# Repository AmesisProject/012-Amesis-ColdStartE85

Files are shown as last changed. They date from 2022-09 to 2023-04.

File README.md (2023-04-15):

# 012-Amesis-ColdStartE85
 Version 1.00 du document ( Vous pouvez me commander des PCB, faites vos demandes à amesisproject@gmail.com)
 
012-Amesis-ColdStartE85
Module d’aide au démarrage à froid pour les moteurs utilisant le carburant Superéthanol E85 dont la cartographie de démarrage à froid n’a pas été réglé.
Les conventions des moteurs à l’éthanol ont généralement un souci mangeur, c’est le ColdStart.

En effet, l’éthanol à son point éclaire à 7 degrés contre -40 pour le super sans plomb. Ce qui entraine donc un démarrage plus difficile voire impossible. 

Module mise au point pour le moteur de Golf IV 1.6L 16v essence passé à l’E85. Equipé du calculateur Magneti Marelli 4MV, mais peut fonctionner sur d’autre model tel quel. A vous d’analyser vos capteurs et signaux pour modifier le code.   

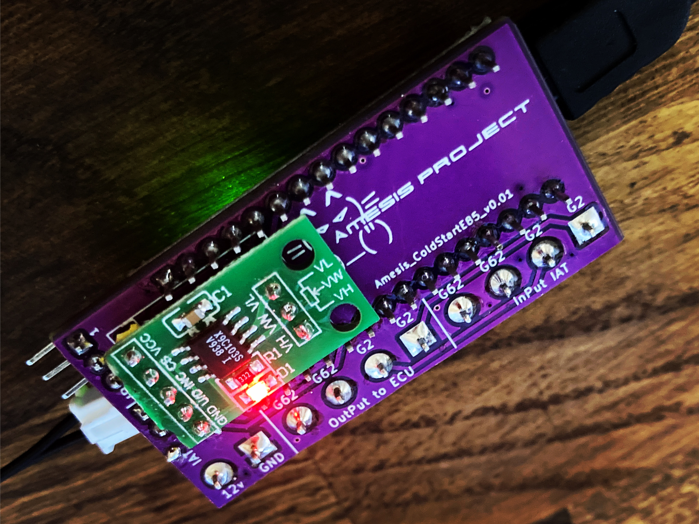
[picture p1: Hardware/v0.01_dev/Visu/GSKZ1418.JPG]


## I Avertissement
 
Ce module n’est nullement homologué, il sera donc fourni à but de test et non à une utilisation sur voie public.
 
Ce module modifiant le signal d’un capteur d’origine, les possibilités d’endommagement de l’ECU ou du moteur reste donc une éventualité. Vous restez seul responsable de l’utilisation de ce module. 
 
Ce module agissant sur des capteurs d’origine du véhicule pourrait entrainer des codes défaut moteur intermittent ou permanant, dans ce cas il est déconseillé de l’utiliser. 
 
Le module a pour but de décaler la plage de temperature du liquide de refroidissement ce qui correspond à des valeurs d’injection et d’allumage plus importante dans les cartographies moteur. Ces cartographies sont généralement très difficiles à modifier car le mappeur doit attendre une température adéquate pour son réglage car le moindre démarrage moteur réchauffe instantanément et rapidement le moteur du fait de la compression de l’air et de la combustion. Il faut attendre plusieurs heures afin de retenter un nouveau réglage, ce qui est parfois laborieux pour les mappeurs. 

C’est donc pour cela que ce module a été créer. 
 
De plus les cartographies de démarrage à froid « cold star » sur les calculateurs ECU Magneti Marelli 4MV sont encore un mystère dans notre communauté.

Cette documentation consterne le module en version matériel 
HW : v0.01dev et logiciel
SW Firmware : v1.031 Béta

Ce module est en version Beta, il sera donc apprécié tout retour d’information positif ou négatif à son sujet pour des nouvelle amélioration matériel et logiciel. 
Vous pouvez nous faire une proposition de modification de cade pas « Pull Requests » de GitHub ou de nous informer sur n’importe quel sujet, problème, bug et améliorations à venir, dans la partie « Issues ». Du repos GitHub du projet « 012-Amesis-ColdStartE85 »
https://github.com/AmesisProject/012-Amesis-ColdStartE85

## II Schéma de câblage
 
Type de branchement possible
Chercher et trouver la sonde de temperature du liquide de refroidissement.
 
La sonde G2 chez le groupe VAG informe la temperature au compteur.
 
La sonde G62 chez le groupe VAG informe la temperature au calculateur moteur (ECU).
 
Pour ce module c’est la sonde de temperature moteur qui nous intéresse. 
 
Ceci a été tester sur une Golf IV 1.6L 16s équipé d’un ECU Magneti Marelli. Ce qui est impotent c’est que la sonde de température du véhicule soit de type NTC c’est à dire que plus elle se réchauffe plus sa résistance réduit (plus elle se rapproche de 0.00 Ohm).
 
Le module doit être raccordé à un plus après contacte et protégé par un fusible 1A (à vérifier suivant la consommation de courant du module) :
 
1)	Sonde à 2 fils (nommer G62 chez le groupe VAG)
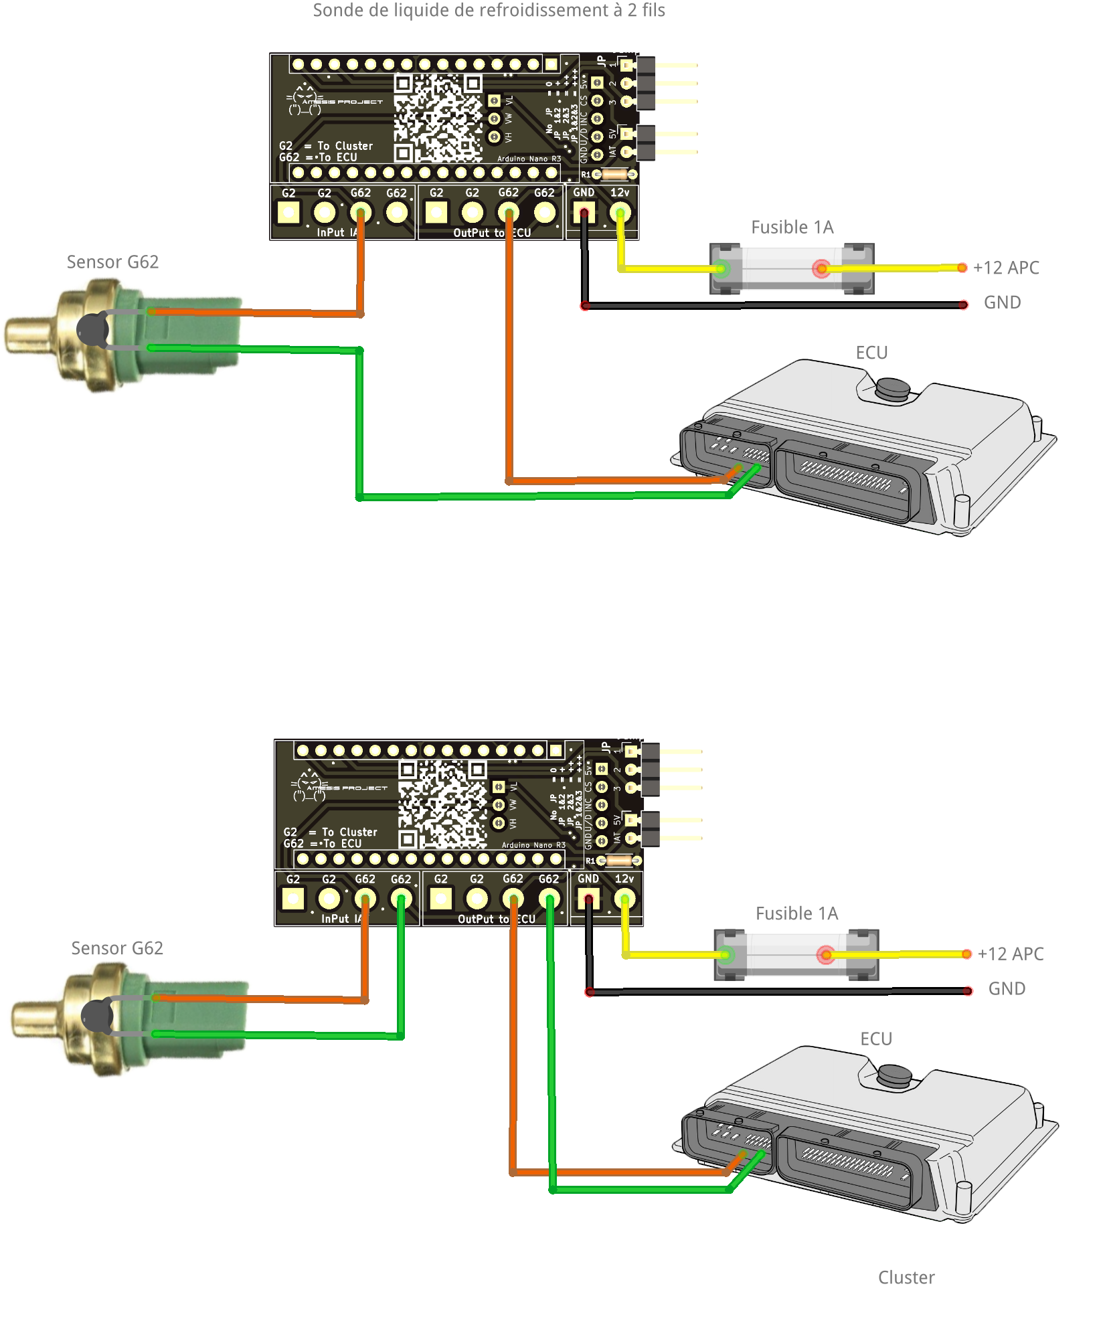
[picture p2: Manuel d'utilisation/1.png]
 
 
2)	Sonde à 4 fils (nommer G2 et G62 chez lez groupe VAG, les deux sondes sont dans le même boitier)
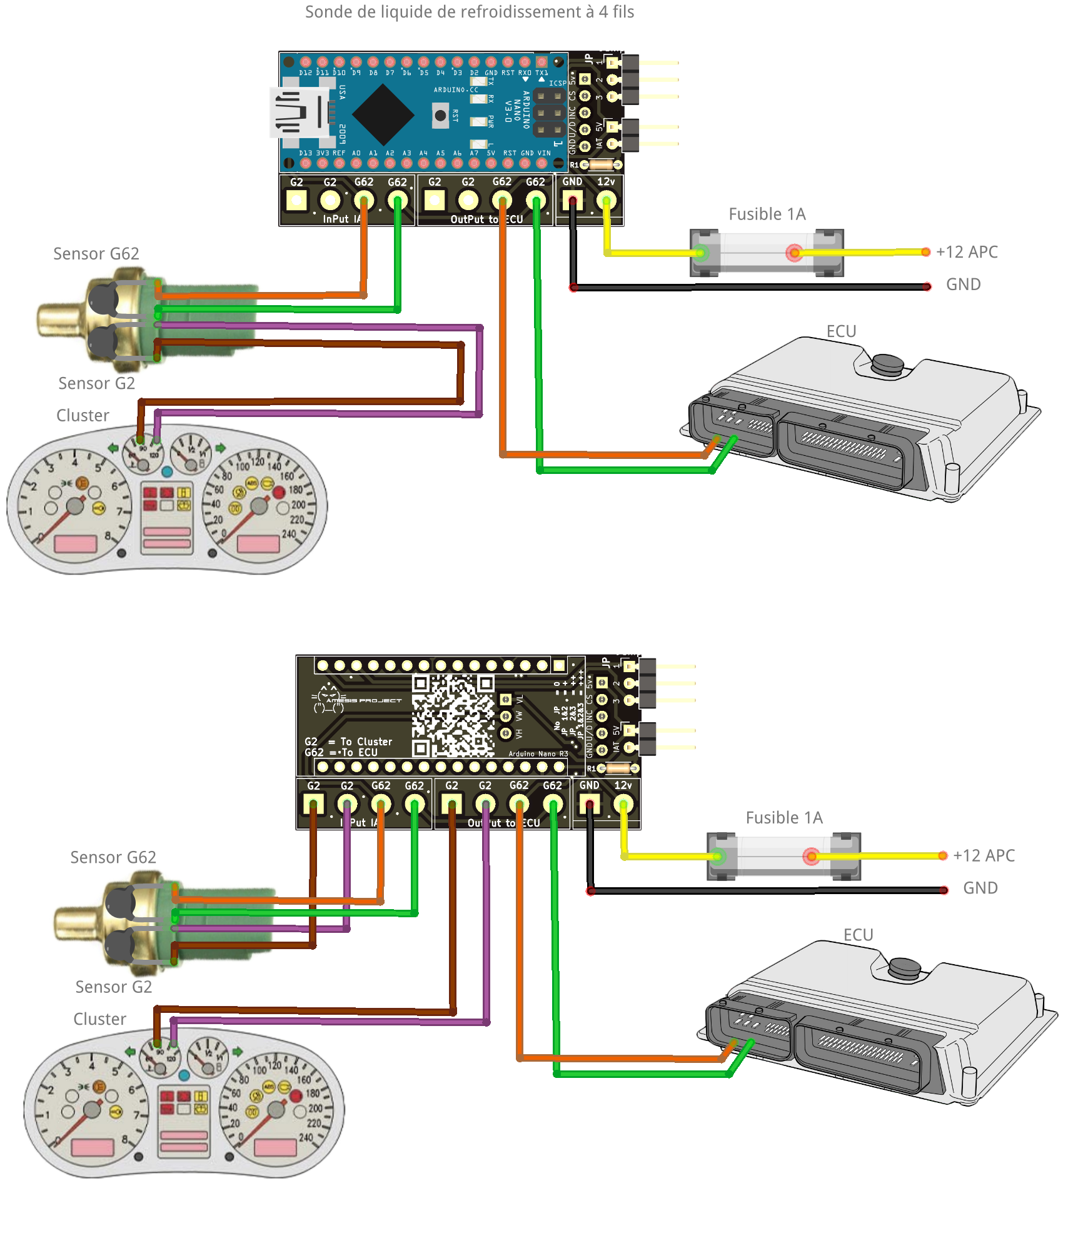
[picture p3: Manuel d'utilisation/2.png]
 

## III Options du module
 
  Le module est équipé des trois Pins accessible, se qui permet de sélectionner les options.
1)	 Option 1
Aucun jumpeur d’installer :
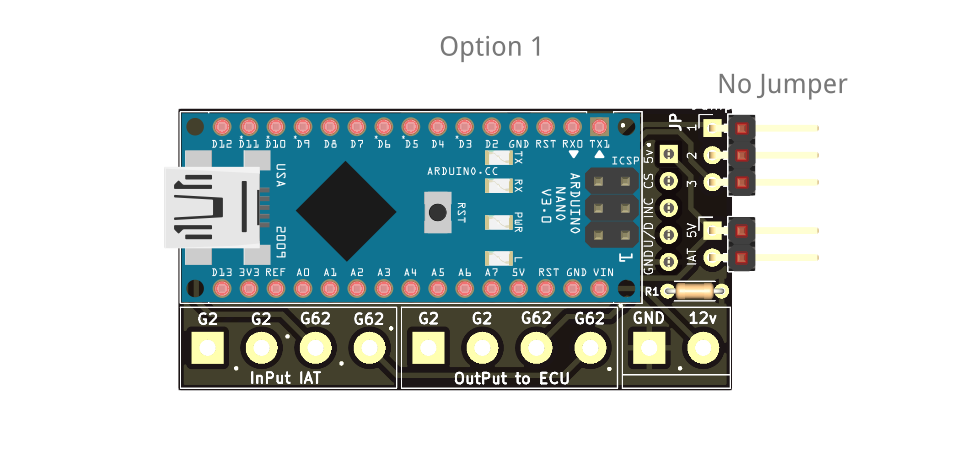
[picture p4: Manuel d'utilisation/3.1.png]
  
Dans ce cas, le module et inactif, une fois le contacte mis, il lesse passe le signal d’origine de la sonde de temperature d’origine.

2)	Option 2
Ponter le jumpeur entre le pin 1 et le pin 2 :
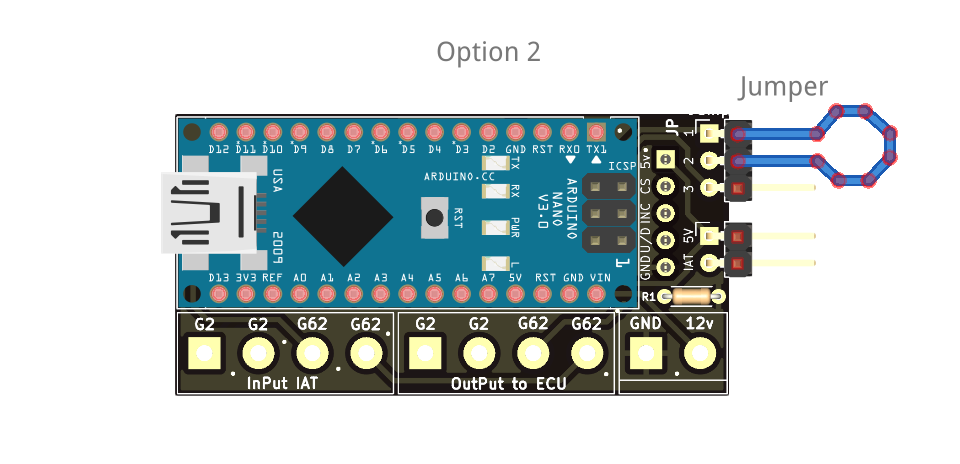
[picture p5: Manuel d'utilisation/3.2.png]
   
Dans ce cas, le module et activer. Il modifie le signal d’origine pour augmenter légèrement l’enrichissement et/ou l’allumage au démarrage.

3)	Option 3
Ponter le jumpeur entre le pin 2 et le pin 3 :
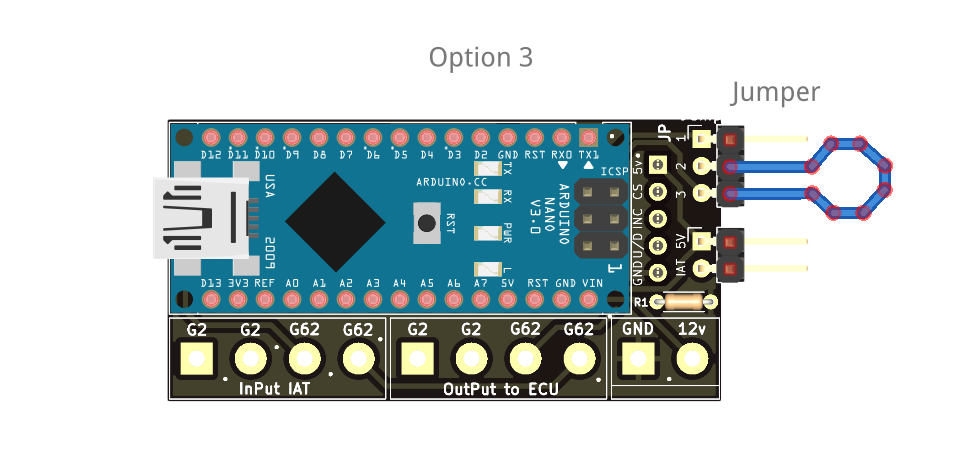
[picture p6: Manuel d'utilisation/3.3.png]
   
Dans ce cas, le module et activer. Il modifie le signal d’origine pour augmenter moyennement l’enrichissement et/ou l’allumage au démarrage.

4)	Option 4
Ponter le jumpeur entre le pin 1, le pin 2 et le pin 3 :
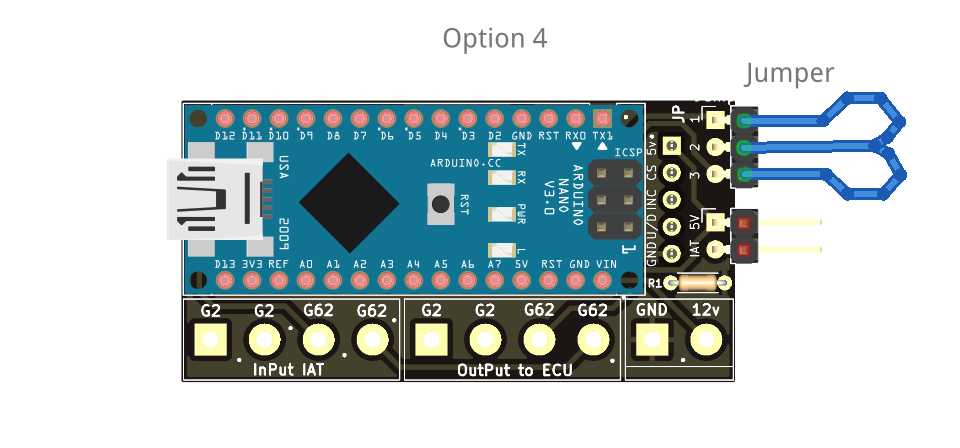
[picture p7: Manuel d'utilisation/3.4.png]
   
Dans ce cas, le module et activer. Il modifie le signal d’origine pour augmenter fortement l’enrichissement et/ou l’allumage au démarrage.
IV Fonctionnement
Une fois le contacte mis, 2 solutions :

1)	Solution 1
Le module n’a pas l’option sonde de temperature additionnelle, dans ce cas, suivant l’option engagée, le module sera actif pendant environ 1 min en modifiant le signe d’origine de manière dégressif jusqu’à atteindre la valeur d’origine après environ 1 min. Passé ce délai, le module passe en mode inactif pour laisser l’ECU d’origine faire son travail normalement.
Sans l’option la sonde de temperature additionnelle le module sera actif à chaque mis sous contacte du véhicule

2)	Solution 2
Le module est équipé de la sonde de temperature additionnelle. Celle-ci devra être placer à proximité d’une source de chaleur venant du moteur, par exemple une durite de liquide de refroidissement du circuit cour. 
La sonde de temperature additionnelle ne doit pas être installer en contacte direct avec des organes du moteur pouvant dépasser une centaine de degré sous peine de risque de détérioration de la sonde voir pire risque d’incendies. 
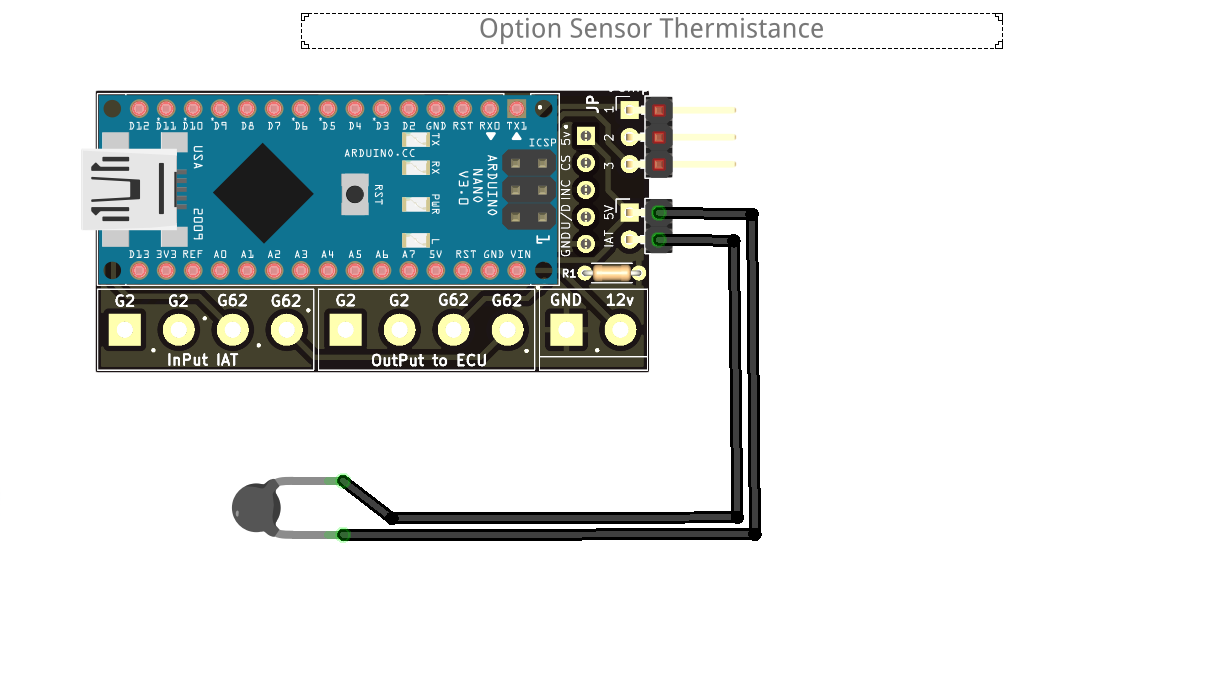
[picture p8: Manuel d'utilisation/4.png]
  
  
Suivant l’option engagé, si le module a bien la sonde de temperature additionnelle, il sera en mesure de comprendre s’il est nécessaire d’activer l’enrichissement à froid suivant la temperature à la sonde de temperature additionnelle.

Pour la version du HW Firmware v1.031 béta, le seuil de d’déclanchement est approximativement en dessous des 30° de la sonde de temperature additionnelle. Si cette valeur et dépassé, alors le module passe en mode inactif car au-delà de cette temperature, le mode enrichissement à froid est inutile.
Cette valeur pourra être ajusté à la demande si besoin par une mise à jour FW.

## V Communication

Le module est pourvu d’un port USB. Il permet de communiquer avec un ordinateur pour contrôler la version du SW HW et les valeurs retournées du module car le décompte du « cold start » et option engagé.

Pour afficher ces valeurs, vous devez vous munir d’un ordinateur Windows, Mac ou Linux avec le logiciel gratuit IDE Arduino d’installer.

Dans le logiciel vous devrez choisir l‘adresse du port USB utilisé par ex :

-Sur Windows Onglet « Outils » -> « Port » -> « Port Com 4 » 

-Puis ouvrir la console de debug avec l’icône loupe en haut à droite de la fenetre du logiciel Arduino.

-Régler la vitesse sur 115200 Baud

Et les valeurs commenceront à défiler dans la fenetre.

ATTENTION Ce logiciel peut écraser les données du microcontrôleur si vous téléverser un nouveau code. 

Il faudra obligatoirement téléverser le code d’origine pour que le module refonctionne normalement.

#Don 

J'ai travaillé ennormement sur ce projet entre le code, la fabrication du PCB et les testes sur la Golf IV 1.6L essese de Mich. Me faire un don me motive pour continuer de mettre en ligne des projets gratuitement.

https://www.paypal.com/donate/?cmd=_s-xclick&hosted_button_id=R9SMSS8L6FZB2&source=url&ssrt=1681586896608

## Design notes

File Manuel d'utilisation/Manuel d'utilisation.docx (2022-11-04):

Version 1.00 du document

012-Amesis-ColdStartE85

Module d’aide au démarrage à froid pour les moteurs utilisant le carburant Superéthanol E85 dont la cartographie de démarrage à froid n’a pas été réglé.

Les conventions des moteurs à l’éthanol ont généralement un souci mangeur, c’est le ColdStart.

En effet, l’éthanol à son point éclaire à 7 degrés contre -40 pour le super sans plomb. Ce qui entraine donc un démarrage plus difficile voire impossible.

Module mise au point pour le moteur de Golf IV 1.6L 16v essence passé à l’E85. Equipé du calculateur Magneti Marelli 4MV, mais peut fonctionner sur d’autre model tel quel. A vous d’analyser vos capteurs et signaux pour modifier le code.

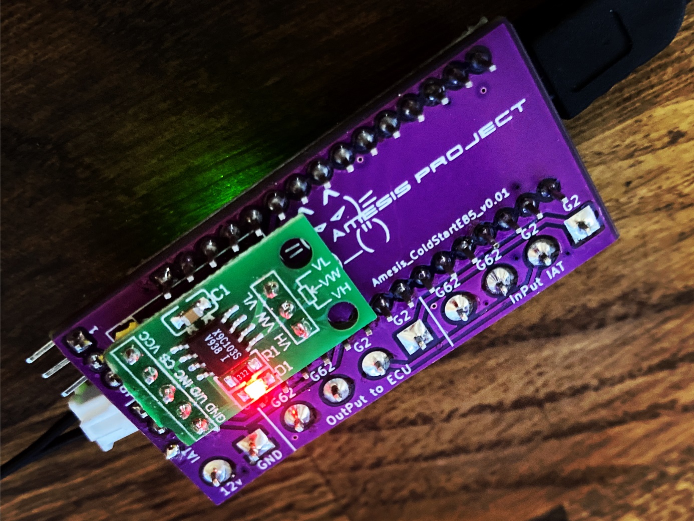
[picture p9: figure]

I Avertissement

Ce module n’est nullement homologué, il sera donc fourni à but de test et non à une utilisation sur voie public.

Ce module modifiant le signal d’un capteur d’origine, les possibilités d’endommagement de l’ECU ou du moteur reste donc une éventualité. Vous restez seul responsable de l’utilisation de ce module.

Ce module agissant sur des capteurs d’origine du véhicule pourrait entrainer des codes défaut moteur intermittent ou permanant, dans ce cas il est déconseillé de l’utiliser.

Le module a pour but de décaler la plage de temperature du liquide de refroidissement ce qui correspond à des valeurs d’injection et d’allumage plus importante dans les cartographies moteur. Ces cartographies sont généralement très difficiles à modifier car le mappeur doit attendre une température adéquate pour son réglage car le moindre démarrage moteur réchauffe instantanément et rapidement le moteur du fait de la compression de l’air et de la combustion. Il faut attendre plusieurs heures afin de retenter un nouveau réglage, ce qui est parfois laborieux pour les mappeurs. C’est donc pour cela que ce module a été créer.

De plus les cartographies de démarrage à froid « cold star » sur les calculateurs ECU Magneti Marelli 4MV sont encore un mystère dans notre communauté.

Cette documentation consterne le module en version matériel

HW : v0.01dev et logiciel

SW Firmware : v1.031 Béta

Ce module est en version Beta, il sera donc apprécié tout retour d’information positif ou négatif à son sujet pour des nouvelle amélioration matériel et logiciel.

Vous pouvez nous faire une proposition de modification de cade pas « Pull Requests » de GitHub ou de nous informer sur n’importe quel sujet, problème, bug et améliorations à venir, dans la partie « Issues ». Du repos GitHub du projet « 012-Amesis-ColdStartE85 »

https://github.com/AmesisProject/012-Amesis-ColdStartE85

II Schéma de câblage

Type de branchement possible

Chercher et trouver la sonde de temperature du liquide de refroidissement.

La sonde G2 chez le groupe VAG informe la temperature au compteur.

La sonde G62 chez le groupe VAG informe la temperature au calculateur moteur (ECU)

Pour ce module c’est la sonde de temperature moteur qui nous intéresse.

Ceci a été tester sur une Golf IV 1.6L 16s équipé d’un ECU Magneti Marelli. Ce qui est impotent c’est que la sonde de température du véhicule soit de type NTC c’est à dire que plus elle se réchauffe plus sa résistance réduit (plus elle se rapproche de 0.00 Ohm)

Le module doit être raccordé à un plus après contacte et protégé par un fusible 1A (à vérifier suivant la consommation de courant du module)

1) Sonde à 2 fils (nommer G62 chez le groupe VAG)

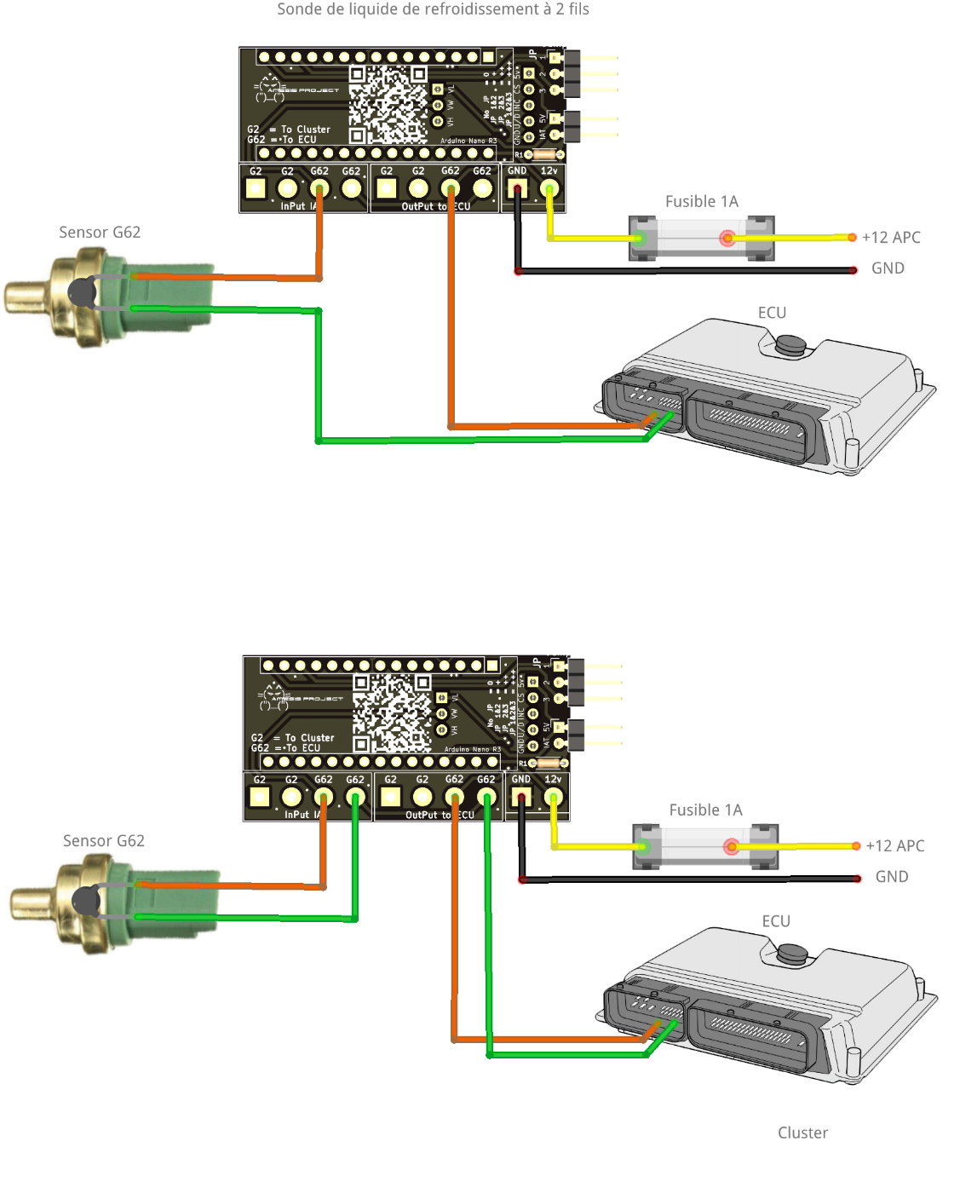
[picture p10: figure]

2) Sonde à 4 fils (nommer G2 et G62 chez lez groupe VAG, les deux sondes sont dans le même boitier)

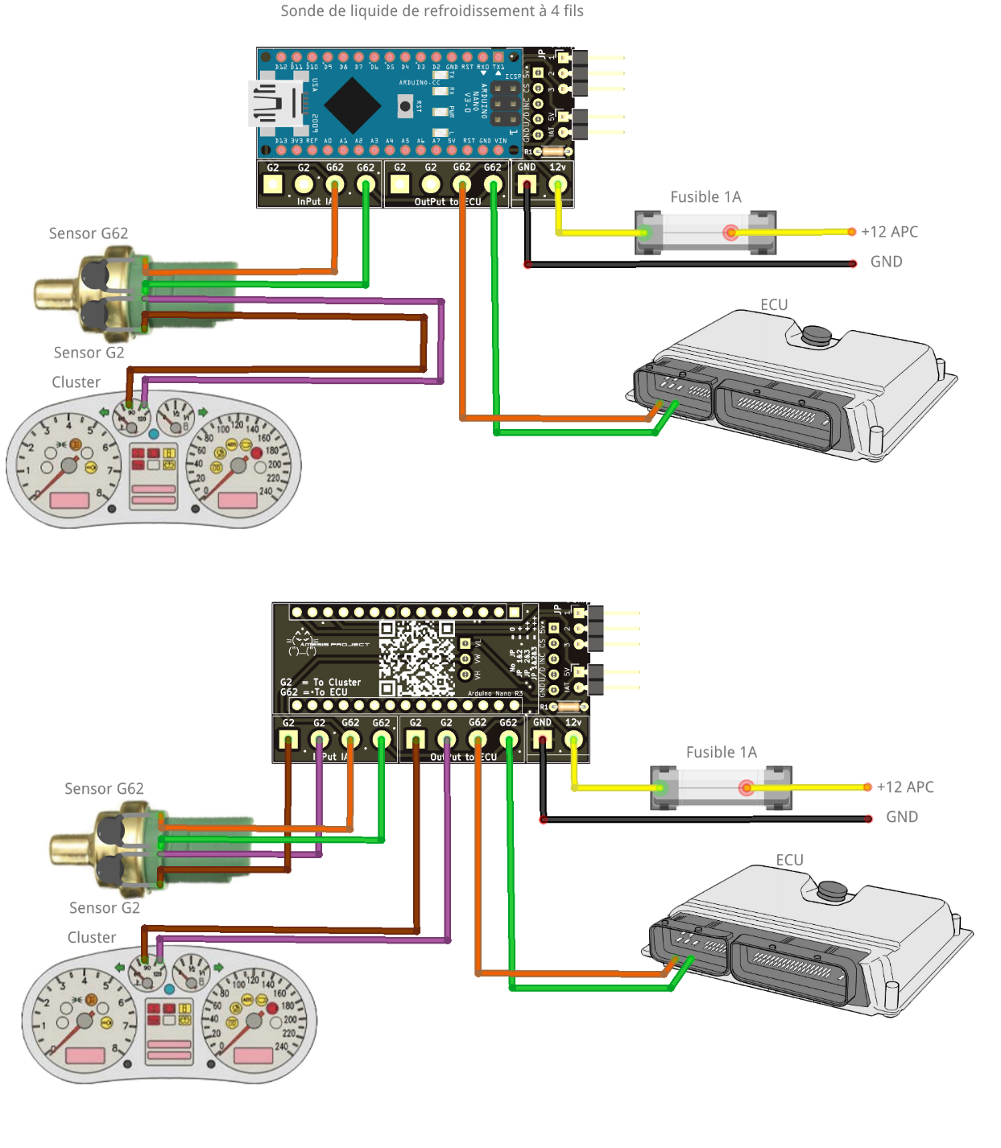
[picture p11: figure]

III Options du module

Le module est équipé des trois Pins accessible, se qui permet de sélectionner les options.

1) Option 1

Aucun jumpeur d’installer :

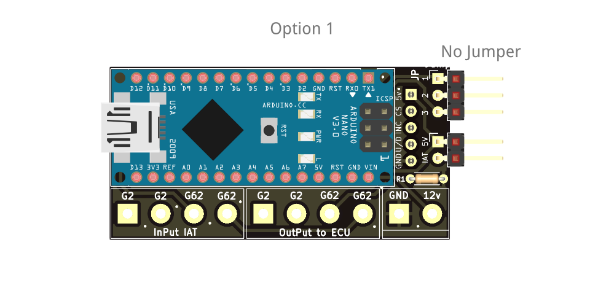
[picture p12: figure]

Dans ce cas, le module et inactif, une fois le contacte mis, il lesse passe le signal d’origine de la sonde de temperature d’origine.

2) Option 2

Ponter le jumpeur entre le pin 1 et le pin 2 :

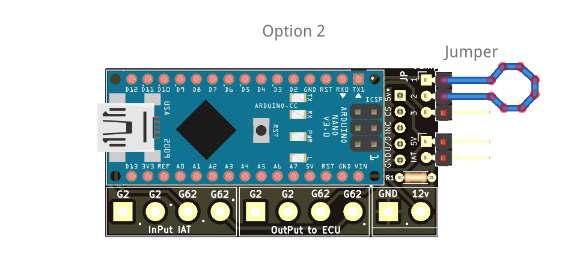
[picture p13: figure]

Dans ce cas, le module et activer. Il modifie le signal d’origine pour augmenter légèrement l’enrichissement et/ou l’allumage au démarrage.

3) Option 3

Ponter le jumpeur entre le pin 2 et le pin 3 :

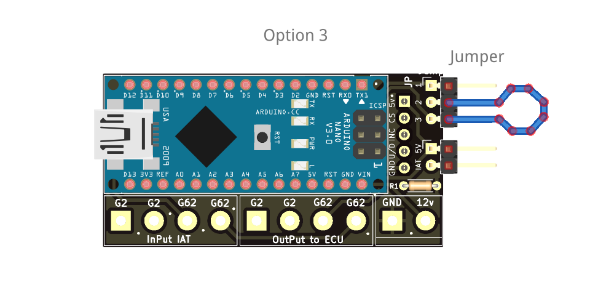
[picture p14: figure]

Dans ce cas, le module et activer. Il modifie le signal d’origine pour augmenter moyennement l’enrichissement et/ou l’allumage au démarrage.

4) Option 4

Ponter le jumpeur entre le pin 1, le pin 2 et le pin 3 :

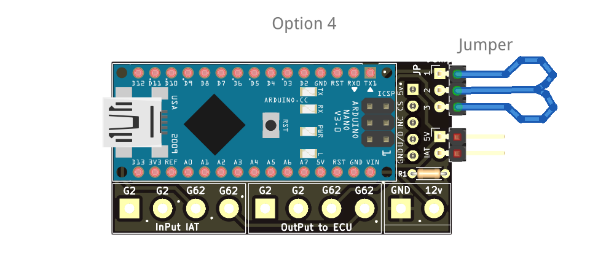
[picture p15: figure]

Dans ce cas, le module et activer. Il modifie le signal d’origine pour augmenter fortement l’enrichissement et/ou l’allumage au démarrage.

IV Fonctionnement

Une fois le contacte mis, 2 solutions :

1) Solution 1

Le module n’a pas l’option sonde de temperature additionnelle, dans ce cas, suivant l’option engagée, le module sera actif pendant environ 1 min en modifiant le signe d’origine de manière dégressif jusqu’à atteindre la valeur d’origine après environ 1 min. Passé ce délai, le module passe en mode inactif pour laisser l’ECU d’origine faire son travail normalement.

Sans l’option la sonde de temperature additionnelle le module sera actif à chaque mis sous contacte du véhicule

2) Solution 2

Le module est équipé de la sonde de temperature additionnelle. Celle-ci devra être placer à proximité d’une source de chaleur venant du moteur, par exemple une durite de liquide de refroidissement du circuit cour.

La sonde de temperature additionnelle ne doit pas être installer en contacte direct avec des organes du moteur pouvant dépasser une centaine de degré sous peine de risque de détérioration de la sonde voir pire risque d’incendies.


Suivant l’option engagé, si le module a bien la sonde de temperature additionnelle, il sera en mesure de comprendre s’il est nécessaire d’activer l’enrichissement à froid suivant la temperature à la sonde de temperature additionnelle.

Pour la version du HW Firmware v1.031 béta, le seuil de d’déclanchement est approximativement en dessous des 30° de la sonde de temperature additionnelle. Si cette valeur et dépassé, alors le module passe en mode inactif car au-delà de cette temperature, le mode enrichissement à froid est inutile.

Cette valeur pourra être ajusté à la demande si besoin par une mise à jour FW.

V Communication

Le module est pourvu d’un port USB. Il permet de communiquer avec un ordinateur pour contrôler la version du SW HW et les valeurs retournées du module car le décompte du « cold start » et option engagé.

Pour afficher ces valeurs, vous devez vous munir d’un ordinateur Windows, Mac ou Linux avec le logiciel gratuit IDE Arduino d’installer.

Dans le logiciel vous devrez choisir l‘adresse du port USB utilisé par ex :

-Sur Windows Onglet « Outils » -> « Port » -> « Port Com 4 »

-Puis ouvrir la console de debug avec l’icône loupe en haut à droite de la fenetre du logiciel Arduino.

-Régler la vitesse sur 115200 Baud

Et les valeurs commenceront à défiler dans la fenetre.

ATTENTION Ce logiciel peut écraser les données du microcontrôleur si vous téléverser un nouveau code. Il faudra obligatoirement téléverser le code d’origine pour que le module refonctionne normalement.

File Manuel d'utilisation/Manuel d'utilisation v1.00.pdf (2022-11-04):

Version 1.00 du document

# 012-Amesis-ColdStartE85

Module d’aide au démarrage à froid pour les moteurs utilisant le carburant Superéthanol E85 dont la cartographie de démarrage à froid n’a pas été réglé.

Les conventions des moteurs à l’éthanol ont généralement un souci mangeur, c’est le ColdStart.

En effet, l’éthanol à son point éclaire à 7 degrés contre -40 pour le super sans plomb. Ce qui entraine donc un démarrage plus difficile voire impossible.

Module mise au point pour le moteur de Golf IV 1.6L 16v essence passé à l’E85. Equipé du calculateur Magneti Marelli 4MV, mais peut fonctionner sur d’autre model tel quel. A vous d’analyser vos capteurs et signaux pour modifier le code.

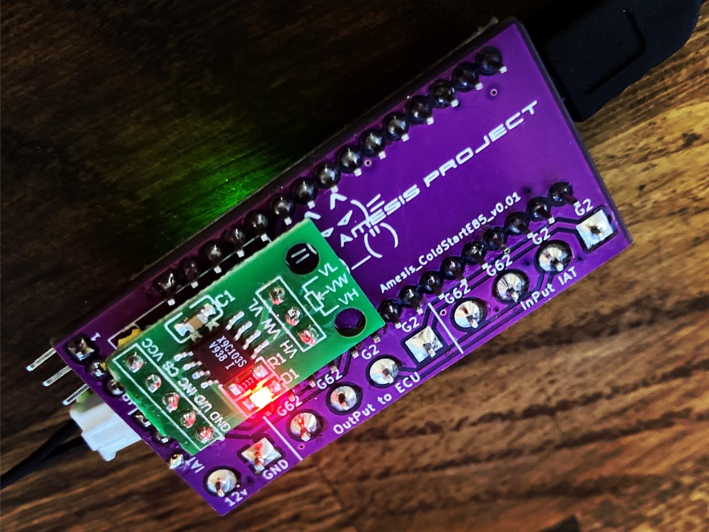
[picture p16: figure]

### I Avertissement

Ce module n’est nullement homologué, il sera donc fourni à but de test et non à une utilisation sur voie public.

Ce module modifiant le signal d’un capteur d’origine, les possibilités d’endommagement de l’ECU ou du moteur reste donc une éventualité. Vous restez seul responsable de l’utilisation de ce module.

Ce module agissant sur des capteurs d’origine du véhicule pourrait entrainer des codes défaut moteur intermittent ou permanant, dans ce cas il est déconseillé de l’utiliser.

Le module a pour but de décaler la plage de temperature du liquide de refroidissement ce qui correspond à des valeurs d’injection et d’allumage plus importante dans les cartographies moteur. Ces cartographies sont généralement très difficiles à modifier car le mappeur doit attendre une température adéquate pour son réglage car le moindre démarrage moteur réchauffe instantanément et rapidement le moteur du fait de la compression de l’air et de la combustion. Il faut attendre plusieurs heures afin de retenter un nouveau réglage, ce qui est parfois laborieux pour les mappeurs. C’est donc pour cela que ce module a été créer.

De plus les cartographies de démarrage à froid « cold star » sur les calculateurs ECU Magneti Marelli 4MV sont encore un mystère dans notre communauté.

Cette documentation consterne le module en version matériel

HW : v0.01dev et logiciel

SW Firmware : v1.031 Béta

Ce module est en version Beta, il sera donc apprécié tout retour d’information positif ou négatif à son sujet pour des nouvelle amélioration matériel et logiciel.

Vous pouvez nous faire une proposition de modification de cade pas « Pull Requests » de GitHub ou de nous informer sur n’importe quel sujet, problème, bug et améliorations à venir, dans la partie
« Issues ». Du repos GitHub du projet « 012-Amesis-ColdStartE85 »

https://github.com/AmesisProject/012-Amesis-ColdStartE85

### II Schéma de câblage

Type de branchement possible

Chercher et trouver la sonde de temperature du liquide de refroidissement.

La sonde G2 chez le groupe VAG informe la temperature au compteur.

La sonde G62 chez le groupe VAG informe la temperature au calculateur moteur (ECU)

Pour ce module c’est la sonde de temperature moteur qui nous intéresse.

Ceci a été tester sur une Golf IV 1.6L 16s équipé d’un ECU Magneti Marelli. Ce qui est impotent c’est que la sonde de température du véhicule soit de type NTC c’est à dire que plus elle se réchauffe plus sa résistance réduit (plus elle se rapproche de 0.00 Ohm)

Le module doit être raccordé à un plus après contacte et protégé par un fusible 1A (à vérifier suivant la consommation de courant du module)

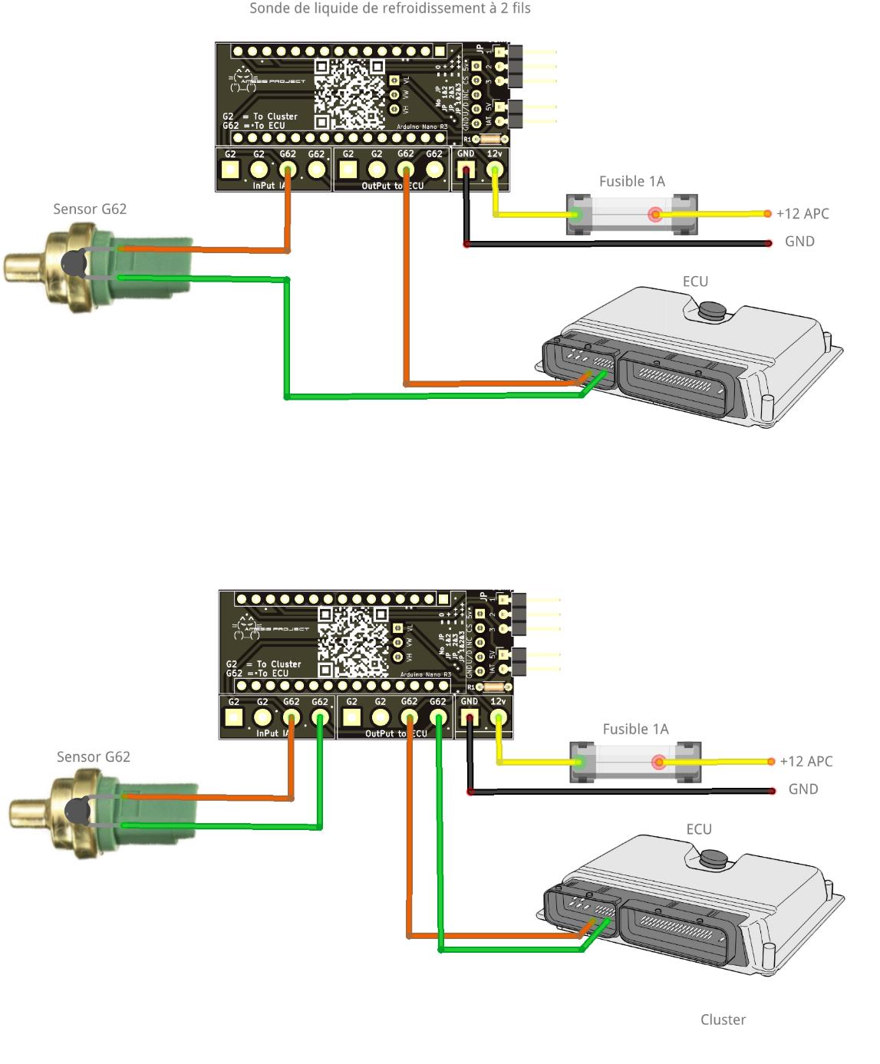
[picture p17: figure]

1) Sonde à 2 fils (nommer G62 chez le groupe VAG)

2) Sonde à 4 fils (nommer G2 et G62 chez lez groupe VAG, les deux sondes sont dans le même boitier)

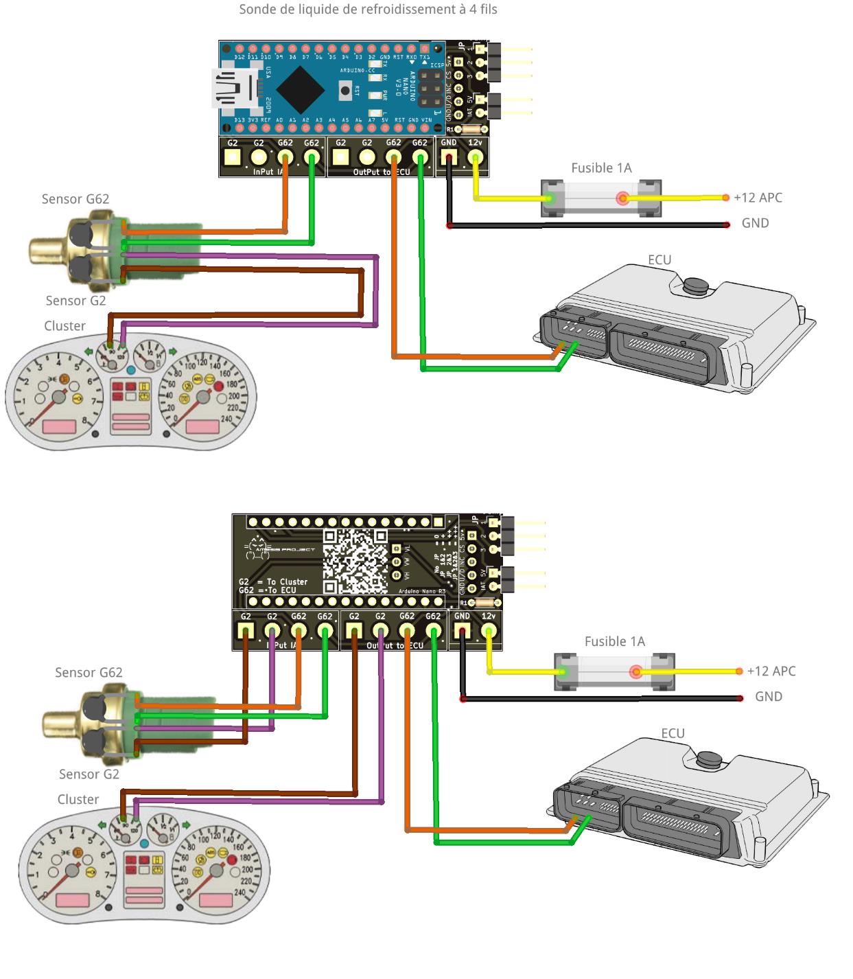
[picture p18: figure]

### III Options du module

Le module est équipé des trois Pins accessible, se qui permet de sélectionner les options.

1) Option 1
Aucun jumpeur d’installer :

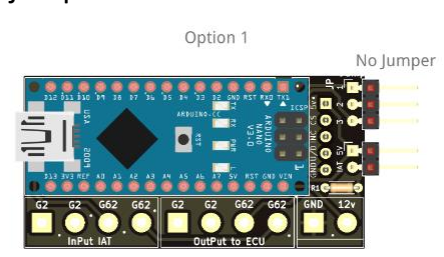
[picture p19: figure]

Dans ce cas, le module et inactif, une fois le contacte mis, il lesse passe le signal d’origine de la sonde de temperature d’origine.

2) Option 2
Ponter le jumpeur entre le pin 1 et le pin 2 :

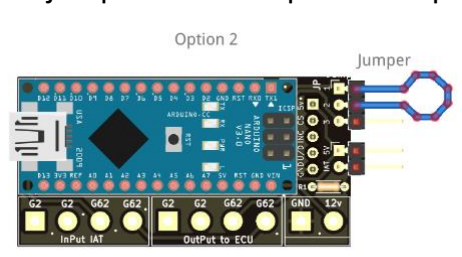
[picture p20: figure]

Dans ce cas, le module et activer. Il modifie le signal d’origine pour augmenter légèrement l’enrichissement et/ou l’allumage au démarrage.

3) Option 3
Ponter le jumpeur entre le pin 2 et le pin 3 :

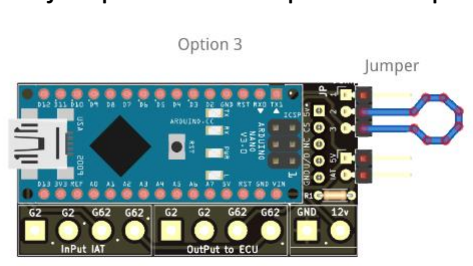
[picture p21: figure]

Dans ce cas, le module et activer. Il modifie le signal d’origine pour augmenter moyennement l’enrichissement et/ou l’allumage au démarrage.

4) Option 4
Ponter le jumpeur entre le pin 1, le pin 2 et le pin 3 :

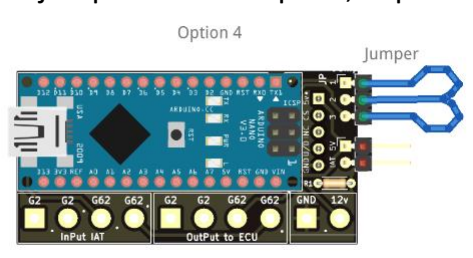
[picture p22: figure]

Dans ce cas, le module et activer. Il modifie le signal d’origine pour augmenter fortement l’enrichissement et/ou l’allumage au démarrage.

### IV Fonctionnement

Une fois le contacte mis, 2 solutions :

1) Solution 1
Le module n’a pas l’option sonde de temperature additionnelle, dans ce cas, suivant l’option engagée, le module sera actif pendant environ 1 min en modifiant le signe d’origine de manière dégressif jusqu’à atteindre la valeur d’origine après environ 1 min. Passé ce délai, le module passe en mode inactif pour laisser l’ECU d’origine faire son travail normalement. Sans l’option la sonde de temperature additionnelle le module sera actif à chaque mis sous contacte du véhicule
2) Solution 2
Le module est équipé de la sonde de temperature additionnelle. Celle-ci devra être placer à proximité d’une source de chaleur venant du moteur, par exemple une durite de liquide de refroidissement du circuit cour.
La sonde de temperature additionnelle ne doit pas être installer en contacte direct avec des organes du moteur pouvant dépasser une centaine de degré sous peine de risque de détérioration de la sonde voir pire risque d’incendies.


Suivant l’option engagé, si le module a bien la sonde de temperature additionnelle, il sera en mesure de comprendre s’il est nécessaire d’activer l’enrichissement à froid suivant la temperature à la sonde de temperature additionnelle.

Pour la version du HW Firmware v1.031 béta, le seuil de d’déclanchement est approximativement en dessous des 30° de la sonde de temperature additionnelle. Si cette valeur et dépassé, alors le module passe en mode inactif car au-delà de cette temperature, le mode enrichissement à froid est inutile.
Cette valeur pourra être ajusté à la demande si besoin par une mise à jour FW.

### V Communication

Le module est pourvu d’un port USB. Il permet de communiquer avec un ordinateur pour contrôler la version du SW HW et les valeurs retournées du module car le décompte du « cold start » et option engagé.

Pour afficher ces valeurs, vous devez vous munir d’un ordinateur Windows, Mac ou Linux avec le logiciel gratuit IDE Arduino d’installer.

Dans le logiciel vous devrez choisir l‘adresse du port USB utilisé par ex :
-Sur Windows Onglet « Outils » -> « Port » -> « Port Com 4 »
-Puis ouvrir la console de debug avec l’icône loupe en haut à droite de la fenetre du logiciel Arduino.
-Régler la vitesse sur 115200 Baud
Et les valeurs commenceront à défiler dans la fenetre.
ATTENTION Ce logiciel peut écraser les données du microcontrôleur si vous téléverser un nouveau code. Il faudra obligatoirement téléverser le code d’origine pour que le module refonctionne normalement.

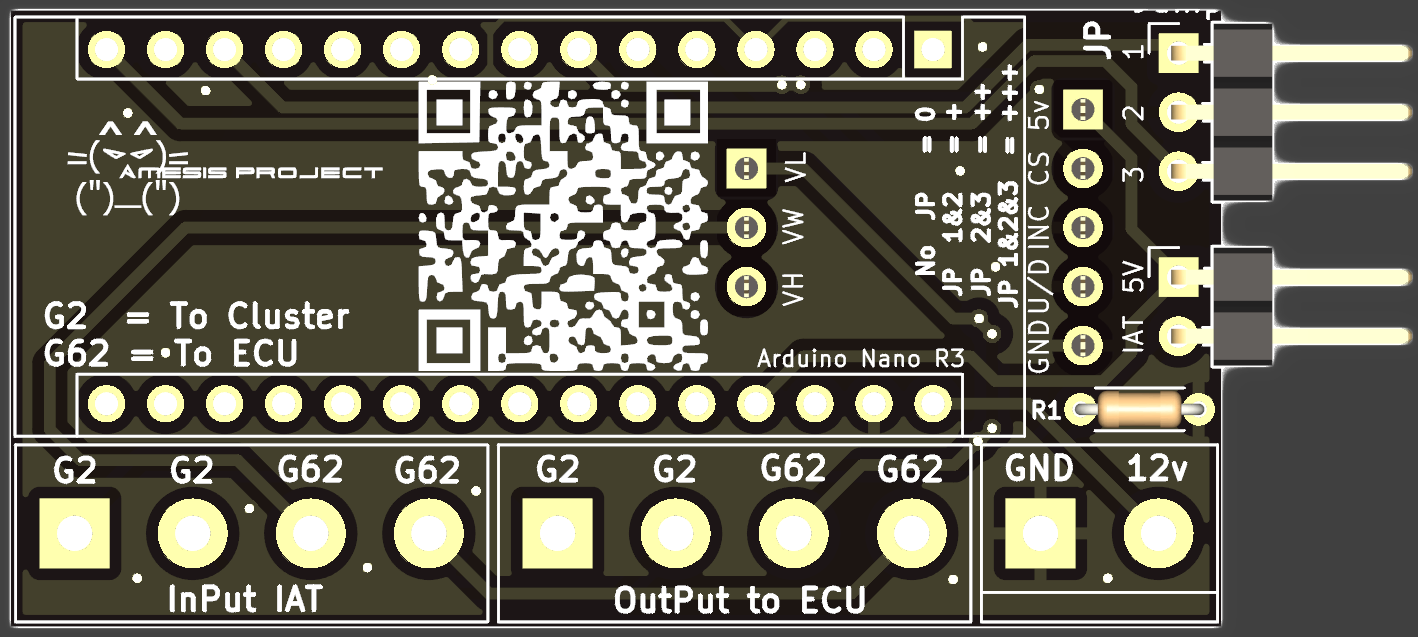
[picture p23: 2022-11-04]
Hardware/v0.01_dev/Visu/012-Amesis-ColdSartE85_HWv0.01.png

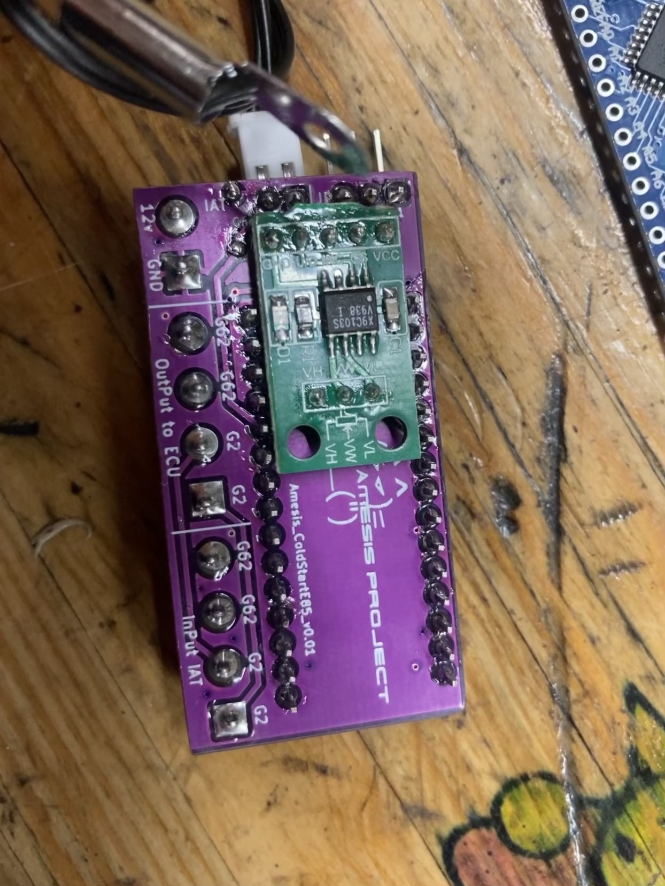
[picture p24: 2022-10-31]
Hardware/v0.01_dev/Visu/IMG_E6661.JPG

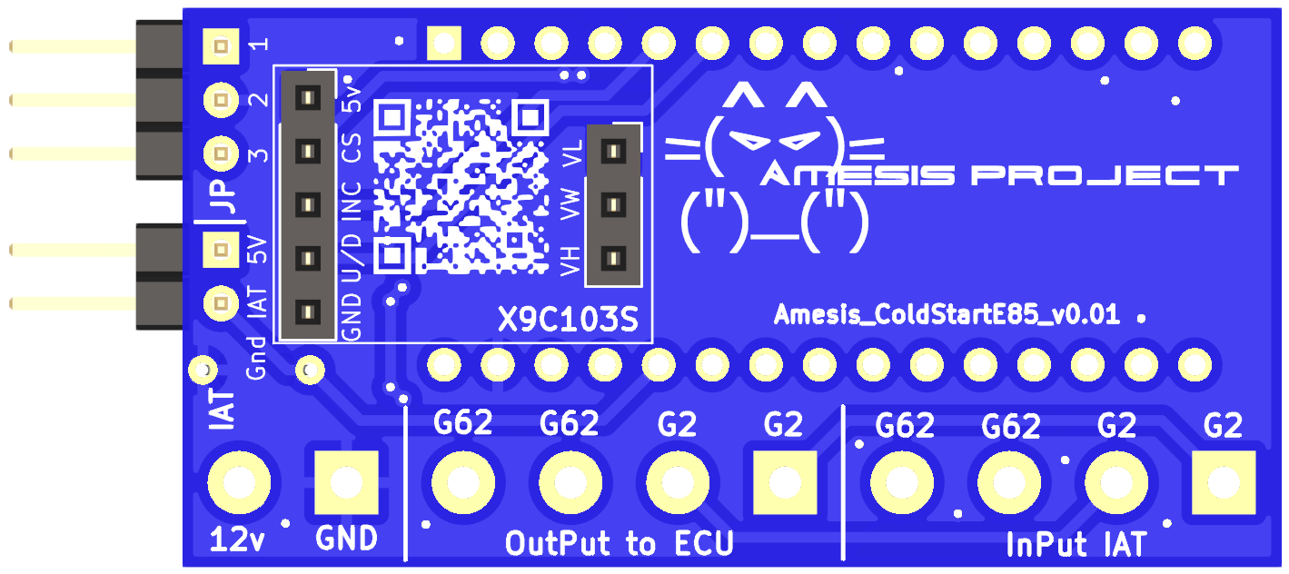
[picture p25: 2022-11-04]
Hardware/v0.01_dev/Visu/012-Amesis-ColdSartE85_HWv0.01 .png

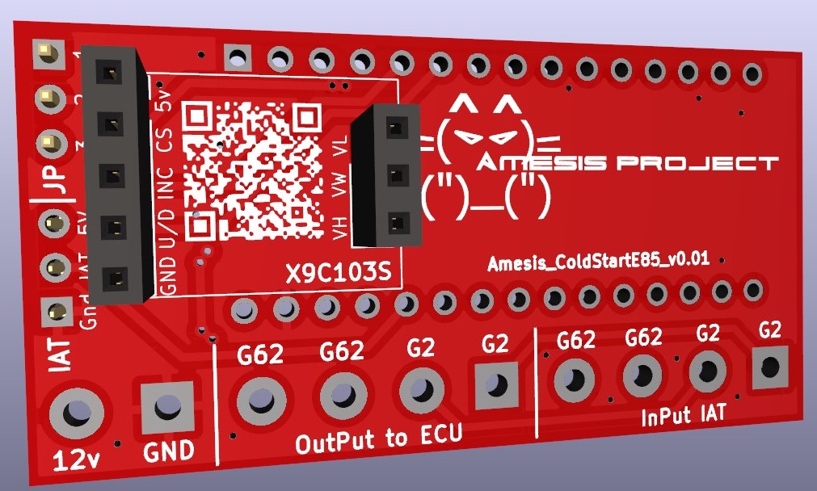
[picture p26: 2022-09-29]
Hardware/v0.01_dev/Visu/verso.jpg

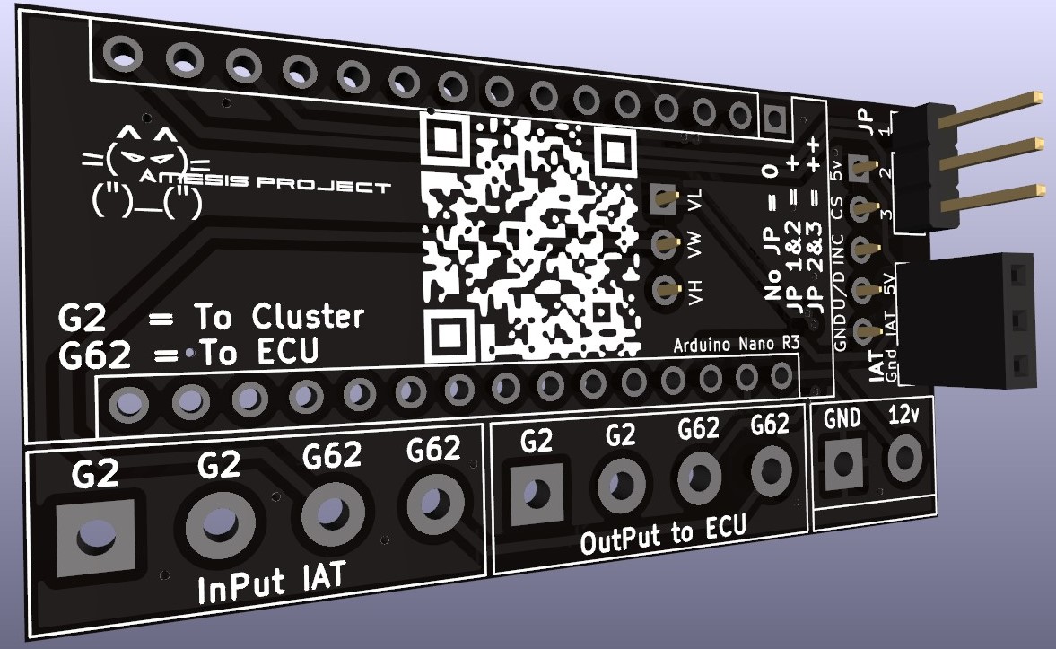
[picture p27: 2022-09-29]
Hardware/v0.01_dev/Visu/Recto.jpg

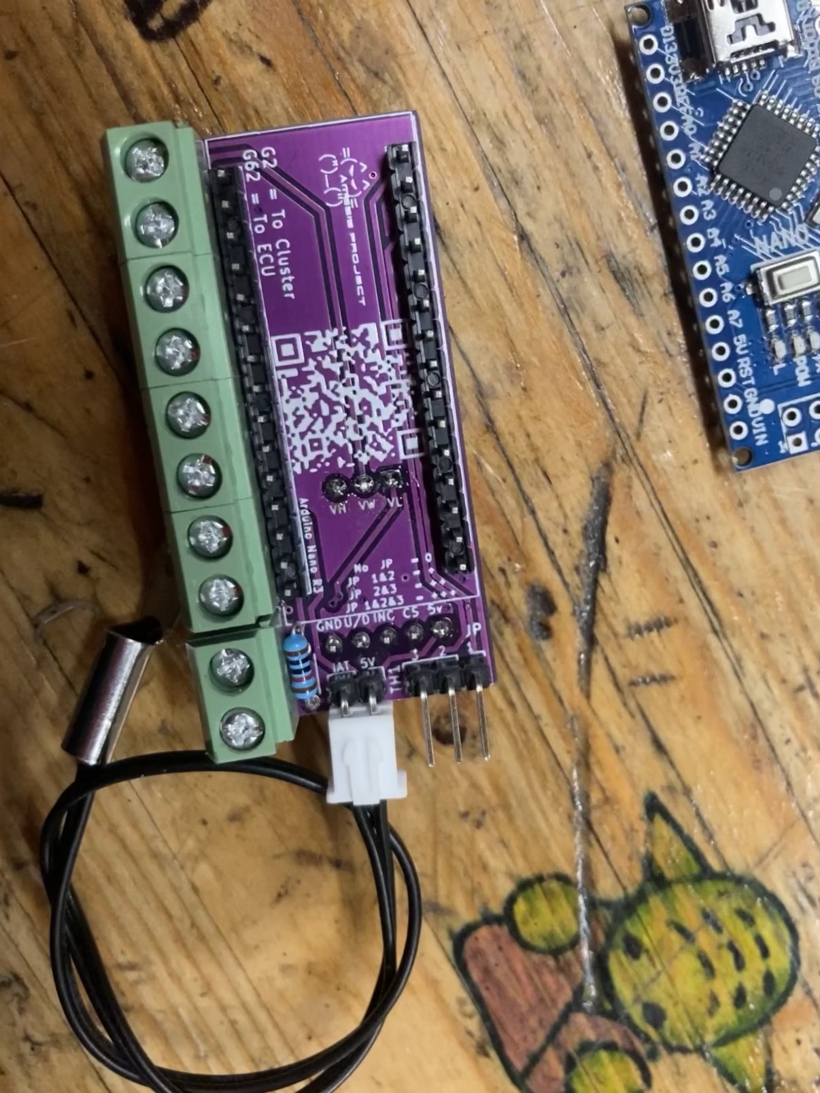
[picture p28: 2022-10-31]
Hardware/v0.01_dev/Visu/IMG_E6660.JPG

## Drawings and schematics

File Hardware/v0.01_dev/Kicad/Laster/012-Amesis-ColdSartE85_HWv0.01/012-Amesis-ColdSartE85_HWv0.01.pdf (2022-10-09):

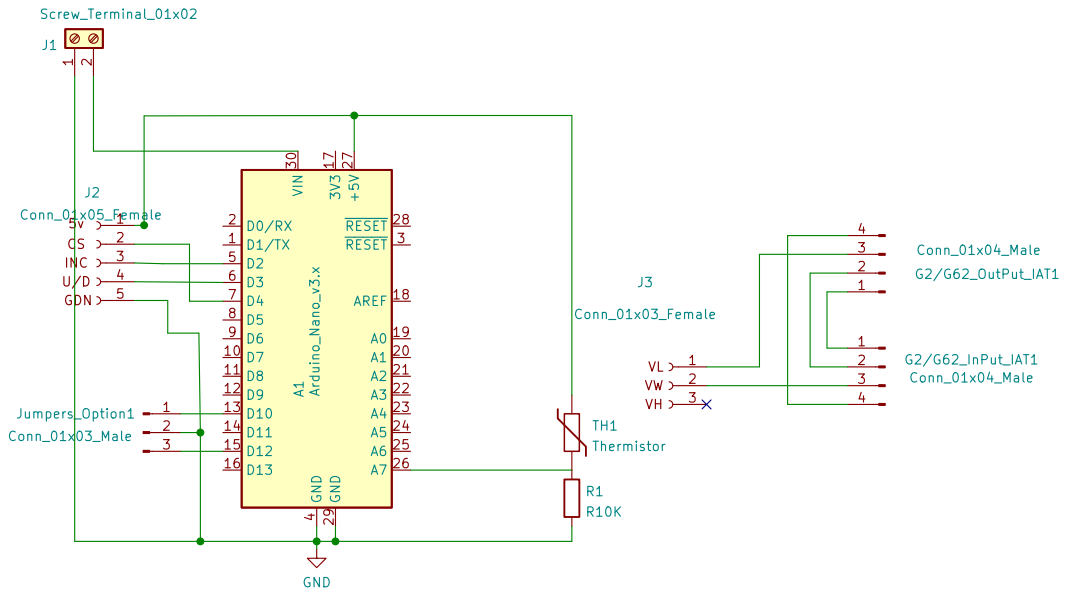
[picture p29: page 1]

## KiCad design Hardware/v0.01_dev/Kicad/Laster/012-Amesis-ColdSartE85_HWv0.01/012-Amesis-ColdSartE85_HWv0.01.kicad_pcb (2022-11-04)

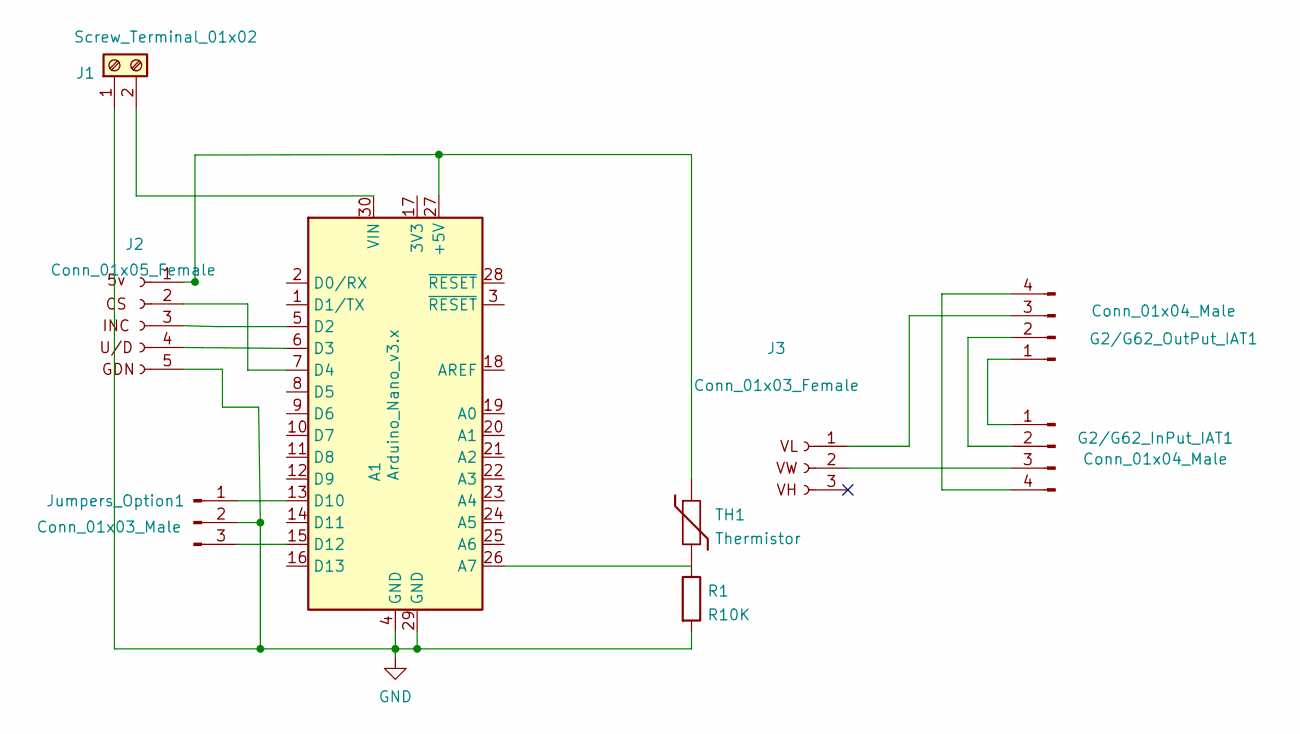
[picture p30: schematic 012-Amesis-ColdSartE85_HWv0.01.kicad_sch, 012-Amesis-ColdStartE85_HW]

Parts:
A1: Arduino_Nano_v3.x; Arduino_Nano
G2/G62_InPut_IAT1, G2/G62_OutPut_IAT1: Conn_01x04_Male; TerminalBlock_bornier-4_P5.08mm
J1: Screw_Terminal_01x02; TerminalBlock_bornier-2_P5.08mm
J2: Conn_01x05_Female; PinSocket_1x05_P2.54mm_Vertical
J3: Conn_01x03_Female; PinSocket_1x03_P2.54mm_Vertical
Jumpers_Option1: Conn_01x03_Male; PinHeader_1x03_P2.54mm_Vertical
R1: R10K; R_Axial_DIN0204_L3.6mm_D1.6mm_P5.08mm_Horizontal
TH1: Thermistor; PinHeader_1x02_P2.54mm_Vertical

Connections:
GND: A1.4 (GND), A1.29 (GND), J1.1, J2.5, Jumpers_Option1.2, R1.2
unnamed: A1.5 (D2), J2.3
unnamed: A1.6 (D3), J2.4
unnamed: A1.7 (D4), J2.2
unnamed: A1.13 (D10), Jumpers_Option1.1
unnamed: A1.15 (D12), Jumpers_Option1.3
unnamed: A1.26 (A7), R1.1, TH1.2
unnamed: A1.27 (+5V), J2.1, TH1.1
unnamed: A1.30 (VIN), J1.2
unnamed: G2/G62_InPut_IAT1.1, G2/G62_OutPut_IAT1.1
unnamed: G2/G62_InPut_IAT1.2, G2/G62_OutPut_IAT1.2
unnamed: G2/G62_InPut_IAT1.3, J3.2
unnamed: G2/G62_InPut_IAT1.4, G2/G62_OutPut_IAT1.4
unnamed: G2/G62_OutPut_IAT1.3, J3.1

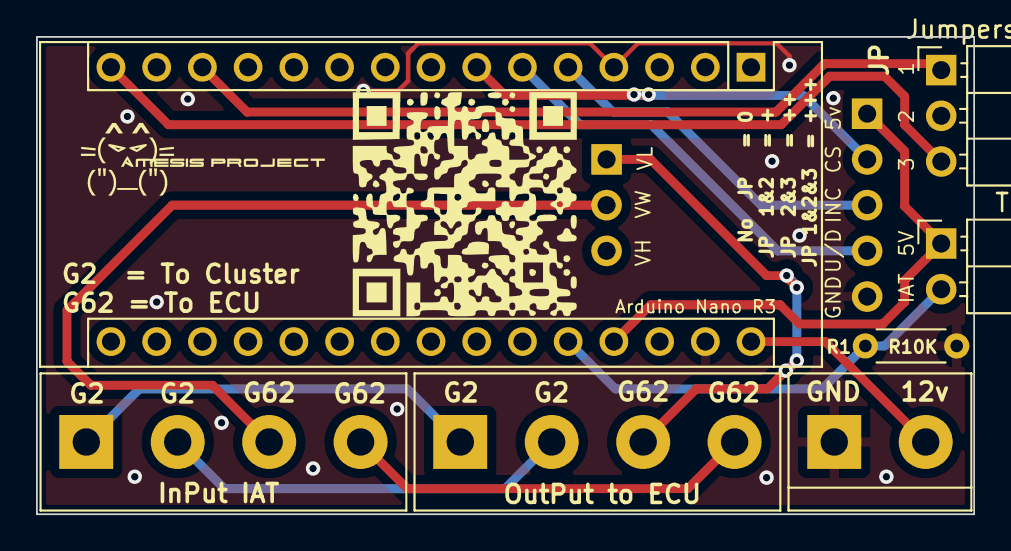
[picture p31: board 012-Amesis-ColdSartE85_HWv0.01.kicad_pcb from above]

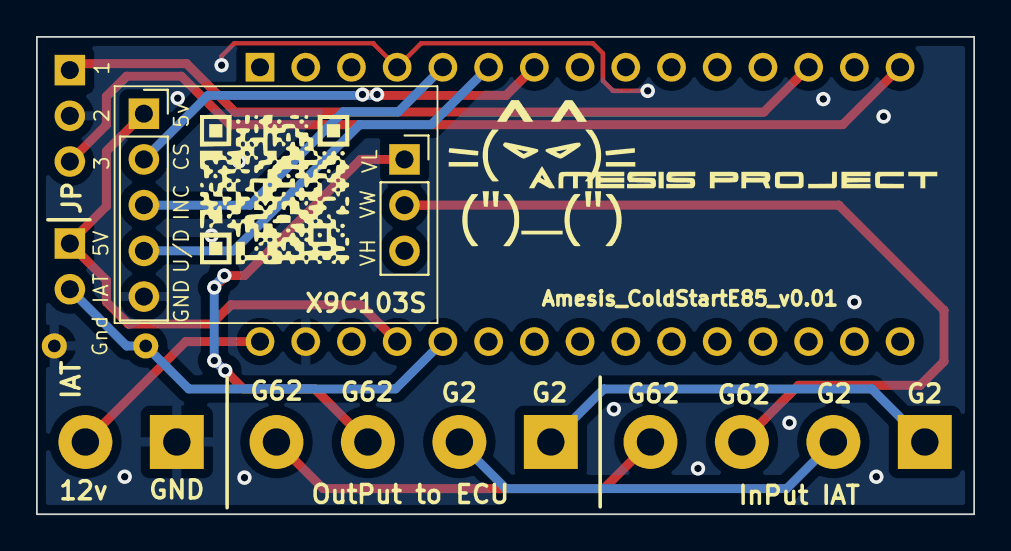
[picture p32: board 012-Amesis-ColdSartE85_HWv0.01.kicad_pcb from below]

Board: 2 copper layers, 52.1 x 26.5 mm, 13 parts (4 on the bottom side), 14 nets.

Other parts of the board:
 : LOGO; 15x15 KiCad QR Code La Boutique Amesis Project
 #2: LOGO; AmesisProject Logo 15mm
 #3: LOGO; AmesisProject Logo 30mm
 #4: LOGO; 10x10 KiCad QR Code La Boutique Amesis Project

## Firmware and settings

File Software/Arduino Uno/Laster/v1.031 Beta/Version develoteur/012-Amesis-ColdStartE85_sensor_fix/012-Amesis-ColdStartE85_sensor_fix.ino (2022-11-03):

//    ^ ^
//  =( '')=
//  ( ")_( ") 
// Amesis Project
// 09/10/2022
// Projet : Amesis-ColdStartE85
// Version SW : v1.031 Beta
// Version HW : v0.01 Dev 
// Description : Ce programme a pour but de hacker une sonde de temperature de liquide de refroidissement pour que les véhicule passers à l'e85 demmarre correctement
//               Nos 1er tests seront réaliser sur une VW Golf IV 1.6L 16v.
//               Le but est de leurer le calculateur en lui faisant croire que la temperature de liquide de refroidissement est extremement froide ce qui change les valeurs
//               choisis dans les cartographies d'injections et d'allumages. 
//               Le code utilise une sonde de temperature pour adapter les valeurs en fonction de la temperature de LR et lisse progressivement le leure.
//  Option 1 : Pas de Jumpers d'installés : Le systeme fait comme si tout été d'orige, aucune resistance de ragoutée
//  Option 2 : Un Jumpeur entre 1 & 2 : ajout d'une resistance faible en plus de la sonde de LR d'origne               
//  Option 3 : Un Jumpeur entre 2 & 3 : ajout d'une resistance mayenne en plus de la sonde de LR d'origine
//  Option 4 : Les deux jumpeurs 1 & 2 & 3 : les valeur maximum sont ajouté en + de la sonde de temparature d'orige.
// Avertissement : Ce système et aucunnement homologué pour une utilisation sur voix public. Il modiffie les données constructeur et 
//                 ceci peut créer un deffaut moteur de temperature valeur de sonde dépassé et autre DTC. Voir la destruction du moteur. Comme ça vous êtes prevenue.
//                 Les valeurs de resistance peuvent être ajuster dans la fonction "void outPutResistanceLap()" dnas le Mapage. Le tebleau de correspondance est affiché en fin de code.  

#include "LapX9C10X.h" //Librairie 

int airTempPin = A7 ;            // A7 Pin de la sonde de temperature d'air 
//int airTempValue ;               // Variable pour la valeur de la temperature 
int ATMin = -90 ;                // Calibration de la sonde de temperature valeur mini
int ATMax = 125 ;                // Calibration de la sonde de temperature valeur Maxi
int ATOffSet = 0;              // L'OffSet est le dacalage de la valeur si besoin d'origine elle est à zéro (provoque un decalage qui perturbe le DTC)
int DTC_AT ;                     // Defaut de la sonde de temperature
int jpOption1Pin = 10 ;          // 10 Pin pour le jumpeur 1
int jpOption1Value ;             // Variable boleene pour le Jumpeur 1
int jpOption2Pin = 12 ;          // 12 Pin pour le jumper 2
int jpOption2Value ;             // Variable boleen pour le Jumpeur 2 
int optionValue ;                // Option engagée pour l'execution du programme 1 2 3 4 
int tempo = 1000 ;               // delais d'une boucle système
int AT_Seuil = 30 ;              // Cette variable est le seuil au dessus dequel le LAP passe a 0 ohms
unsigned long coldStart = 60000 ;// Temps du ColdStart avant de basculer un valeur d'origine en ms

//Pour ce programme le module potentiometre numerique LAPX9C103 10Kohms à été choisis (Pour les autres variantes,Changez la valeur dans la ligne : LapX9C10X led(INCPIN, UDPIN, CSPIN, LAPX9C10X_X9C103);) 
//Pins de comunication entre l'arduino et le module LAPX9C103
#define CSPIN 4   // 1 - !INC - pin 7
#define INCPIN 2  // 2 - U/!D - pin 5
#define UDPIN 3   // 7 - !CS  - pin 6
LapX9C10X led(INCPIN, UDPIN, CSPIN, LAPX9C10X_X9C103); // * LAPX9C10X_X9C102(1k)  * LAPX9C10X_X9C103(10k) * LAPX9C10X_X9C503(50k) * LAPX9C10X_X9C104(100k)
int counter; //variable pour envoyer la commande au modul LAP
float resistance; //variable qui retourne l'info de la resistance choisis venant du LAP

//TO DO 
//Ces variable sont lier a le fonction void degre() qui semble très interresente pour le calibrage des sonde AirTemperature Mais pas utilisé dans cette V1.00 Beta
//Fonction pour les valeur en degré C° pour la fonction "void degre()"
int Vo;
float R1 = 10000;
float logR2, R2, T, airTempValue;
float c1 = 1.009249522e-03, c2 = 2.378405444e-04, c3 = 2.019202697e-07;

//Initialisation du programme
void setup(){
  airTempValue = 0 ;// Initialisation
  optionValue = 0 ; // Initialisation

  pinMode (jpOption1Pin, INPUT_PULLUP) ; //Declaration de entré Jumpeur un PullUp
  pinMode (jpOption2Pin, INPUT_PULLUP) ; //Declaration de entré Jumpeur un PullUp

 led.begin(-1); // Initialisation à 0 Ohms du modul LAPX9C103
 // delay(50);
  
  Serial.begin(115200);  // Initialisation de la liaison serie 
  Serial.println("Demarrage du système "); 
  Serial.println("09/10/2022 Projet : Amesis-ColdStartE85  SW Firmware Version : v1.031 Beta | HW : v0.01Dev");
 // delay(50); 
 
}

//Demmarage du programme
void loop(){

 unsigned long currentMillis = millis(); // Enregistrement de la date pour le temps du coldStart non bloquante

 option(); // Appel a la fonction option -- Il y a 4 options dans ce programme suivant le positionnement des jumpers sur le HW / L'option 1 ne fais rien elle lesse la continuité du fils pour avoir 0 ohms
  Serial.println ("");
  Serial.print ("Option ");
  Serial.print (optionValue);
  Serial.println (" activée ");

 DTC(); //Appel a la fonction DTC
   if (DTC_AT == 1) { //Si il n'y a pas l'option sonde de temperature du module
        Serial.println ("ColdStart Sans option de sonde de temperature"); 
        
        if (optionValue == 4){
            counter = 99 ; 
            
            for (int i=0; i<99; i++) { // Incrementation de 99 car le LAP a une plage de 0 à 99
              counter = counter - 1 ; // on enlève 1 a counter pour rappel counter 99 = 100K ohms 0 = 0 ohm (voire tableau en fin de code)
              Serial.print ("Le counter = ") ;
              Serial.println (counter) ;
              led.set(counter);
              delay (coldStart/60) ; // delay pour la boucle for en fonction du delay du coldStart choisi dans la declaration des variables
              }
            for (int j=0; j<1;){ // boucle for pour verouiller la boucle et ne plus en sortir.
              Serial.println ("Fin du mode ColdStart");
              counter = 0 ;  
              led.set(counter);
              delay (600); // ce chiffre est calculer en faisent 60/100= 0,6s 60seconde / 100 tour de boucle for = 0.6s 
              }
        }
        else if (optionValue == 3){
                 counter = 69 ; 
           
                 for (int i=0; i<69; i++) { // Incrementation de 99 car le LAP a une plage de 0 à 69
                   counter = counter - 1 ; // on enlève 1 a counter pour rappel counter 99 = 100K ohms 0 = 0 ohm (voire tableau en fin de code)
                   Serial.print ("Le counter = ") ;
                   Serial.println (counter) ;
                   led.set(counter);
                   delay (coldStart/60) ; // delay pour la boucle for en fonction du delay du coldStart choisi dans la declaration des variables
                   }
                for (int j=0; j<1;){ // boucle for pour verouiller la boucle et ne plus en sortir.
                  Serial.println ("Fin du mode ColdStart");
                  counter = 0 ;  
                  led.set(counter);
                  delay (869);
                  }
        }
        else if (optionValue == 2){
                 counter = 39 ; 
                
                for (int i=0; i<39; i++) { // Incrementation de 39 car le LAP a une plage de 0 à 99
                  counter = counter - 1 ; // on enlève 1 a counter pour rappel counter 99 = 100K ohms 0 = 0 ohm (voire tableau en fin de code)
                  Serial.print ("Le counter = ") ;
                  Serial.println (counter) ;
                  led.set(counter);
                  delay (coldStart/60) ; // delay pour la boucle for en fonction du delay du coldStart choisi dans la declaration des variables
                  }
               for (int j=0; j<1;){ // boucle for pour verouiller la boucle et ne plus en sortir.
                 Serial.println ("Fin du mode ColdStart");
                 counter = 0 ;  
                 led.set(counter);
                 delay (1538);
                 }
        }
         else if (optionValue == 1){
                 counter =  0; 
               
               for (int j=0; j<1;){ // boucle for pour verouiller la boucle et ne plus en sortir.
                 Serial.println ("Fin du mode ColdStart");
                 counter = 0 ;  
                 led.set(counter);
                 delay (1538);
                 }
        }
 }
 else if (currentMillis < coldStart){
  Serial.println ("ColdStart = ON");

 outPutResistanceLap(); // Appel de la fonction 
  Serial.print ("une résistance de sortie du module est de ");
  Serial.print (led.getK());
  Serial.println (" Khoms");
 }
  else {
    Serial.println ("ColdStart = OFF");
  int counter;      // Le int sert pour le microcontroleur du modul LAPX9C10X_X9C103
  float resistance; // Le float sert pour le microcontroleur du modul LAPX9C10X_X9C103
  counter = 0 ;     //On ecrit la valeur du counter de 0 à 99 Mapé 0 Ohms à 10K Ohms(Voire tableau de correspondance en bas de code)
    led.set(counter);
    Serial.print ("Le programme ce deroule sans ajout, la resistance du module est de ");
    Serial.print (led.getK());
    Serial.println ("Khoms");
  }
  Serial.print ("Il s'est écoulé ");
  Serial.print (currentMillis / 1000); 
  Serial.println ("s depuis le contacte mis");
  Serial.println ("_____________________________________________________");
  delay(tempo);
}

void option(){

  // Pin entré pour jumper
  jpOption1Value = digitalRead(jpOption1Pin) ;
  jpOption2Value = digitalRead(jpOption2Pin) ;

  if (jpOption1Value == LOW & jpOption2Value == LOW) {// Option 4 Avec les 2 jumpeurs d'installé entre 1 & 2 et 2 & 3
     //Serial.println ("Option 4 +++ ");
     optionValue = 4 ;
       } 

 else if (jpOption2Value == LOW ) {// Option 3 Avec le jumpeur entre 2 & 3
       // Serial.println ("Option 3 ++ ");
        optionValue = 3 ;
       }        
                          
 else if (jpOption1Value == LOW ) {
        //Serial.println ("Option 2 + ");// Option 1 Avec le jumper entre 1 & 2
        optionValue = 2 ;
       }

 else if (jpOption1Value == HIGH & jpOption2Value == HIGH) {
        //Serial.println ("Option 1 ");
        optionValue = 1 ; // Option 0 Sans jumper

       }  
       return (optionValue);
}

void outPutResistanceLap(){
 //Sonde airTemp ext 
 degre();

  Serial.print ("La temperature exterieur est de "); //a desactiver pour la version client
  Serial.print (airTempValue); //Affiche sur le port serie la valeur de la variable
  Serial.println ("C° ");
  
  //int counter;      // Le int sert pour le microcontroleur du modul LAPX9C10X_X9C103
  //float resistance; // Le float sert pour le microcontroleur du modul LAPX9C10X_X9C103
         if (optionValue  == 4){ //Si Option 4 est enclanchée 
               if (airTempValue <= 0) { counter = 99 ; }   //sinon on met au max de l'option 4    
          else if (airTempValue > 0 && airTempValue < AT_Seuil) {counter = map(airTempValue, ATMin, ATMax, 99, 69);} //on mets le counter mapé avec les valeurs entre ()
          else if (airTempValue >= AT_Seuil) { counter = 0  ; }   //Sinon on met le LAP à 0 ohms   Cette ligne peut être commenté pour ne pas limité 
           }

    else if (optionValue  == 3){ //Si Option 3 est enclanchée 
               if (airTempValue <= 0) { counter = 69 ; }          //sinon on met au max de l'option 3 
          else if (airTempValue > 0 && airTempValue < AT_Seuil) {counter = map(airTempValue, ATMin, ATMax, 69, 39);} //on mets le counter mapé avec les valeurs entre ()
          else if (airTempValue >= AT_Seuil) { counter = 0  ; }   //Sinon on met le LAP à 0 ohms   Cette ligne peut être commenté pour ne pas limité   
          } 

    else if (optionValue  == 2){ //Si Option 2 est enclanchée
               if (airTempValue <= 0) { counter = 39 ; }         //sinon on met au max de l'option 2 
          else if (airTempValue > 0 && airTempValue < AT_Seuil) {counter = map(airTempValue, ATMin, ATMax, 39, 9);} //on mets le counter mapé avec les valeurs entre ()
          else if (airTempValue >= AT_Seuil) { counter = 0  ; }   //Sinon on met le LAP à 0 ohms   Cette ligne peut être commenté pour ne pas limité   
          }

    else if (optionValue  == 1) {counter = 0 ;} //Si Option 1 est enclanchée on mets le counter a 0 ce qui équivau a une resistance du Lap de 0 ohms

  Serial.print("Le counter = ");
  Serial.print(counter);
  led.set(counter); //On envoie la variable au module LAP
  Serial.println(" ce qui équiveau à ");
  return (led.getK());
}

void degre (){// Cette fonction n'est pas exploitée pour le moment 

  Vo = analogRead(airTempPin);
  R2 = R1 * (1023.0 / (float)Vo - 1.0);
  logR2 = log(R2);
  T = (1.0 / (c1 + c2*logR2 + c3*logR2*logR2*logR2));
  airTempValue = T - 273.15 + ATOffSet;
  
  return(airTempValue);

}

void DTC(){
       if (airTempValue == ATMin) {DTC_AT = 1 ;} //Si la valeur min à été atteinte alors defaut 
  else if (airTempValue == ATMax) {DTC_AT = 1 ;} //Si la valeur max à été atteinte alors defaut 
  else {DTC_AT = 0 ;}                            //Sinon pas de defaut

  Serial.print ("DTC = ");
  Serial.println (DTC_AT);

 return (DTC_AT);
}

/** Tableau de correspondance :
01:14:21.757 -> Starting, set to minimum resistance
01:14:26.820 -> Using absolute counter changes
01:14:26.820 -> Increasing, counter = 0, new resistance = 0.00KOhms
01:14:26.914 -> Increasing, counter = 1, new resistance = 0.10KOhms
01:14:27.007 -> Increasing, counter = 2, new resistance = 0.20KOhms
01:14:27.100 -> Increasing, counter = 3, new resistance = 0.30KOhms
01:14:27.240 -> Increasing, counter = 4, new resistance = 0.40KOhms
01:14:27.333 -> Increasing, counter = 5, new resistance = 0.51KOhms
01:14:27.425 -> Increasing, counter = 6, new resistance = 0.61KOhms
01:14:27.518 -> Increasing, counter = 7, new resistance = 0.71KOhms
01:14:27.612 -> Increasing, counter = 8, new resistance = 0.81KOhms
01:14:27.749 -> Increasing, counter = 9, new resistance = 0.91KOhms
01:14:27.841 -> Increasing, counter = 10, new resistance = 1.01KOhms
01:14:27.935 -> Increasing, counter = 11, new resistance = 1.11KOhms
01:14:28.030 -> Increasing, counter = 12, new resistance = 1.21KOhms
01:14:28.123 -> Increasing, counter = 13, new resistance = 1.31KOhms
01:14:28.216 -> Increasing, counter = 14, new resistance = 1.41KOhms
01:14:28.356 -> Increasing, counter = 15, new resistance = 1.52KOhms
01:14:28.449 -> Increasing, counter = 16, new resistance = 1.62KOhms
01:14:28.540 -> Increasing, counter = 17, new resistance = 1.72KOhms
01:14:28.634 -> Increasing, counter = 18, new resistance = 1.82KOhms
01:14:28.727 -> Increasing, counter = 19, new resistance = 1.92KOhms
01:14:28.864 -> Increasing, counter = 20, new resistance = 2.02KOhms
01:14:28.957 -> Increasing, counter = 21, new resistance = 2.12KOhms
01:14:29.050 -> Increasing, counter = 22, new resistance = 2.22KOhms
01:14:29.144 -> Increasing, counter = 23, new resistance = 2.32KOhms
01:14:29.238 -> Increasing, counter = 24, new resistance = 2.42KOhms
01:14:29.331 -> Increasing, counter = 25, new resistance = 2.53KOhms
01:14:29.471 -> Increasing, counter = 26, new resistance = 2.63KOhms
01:14:29.564 -> Increasing, counter = 27, new resistance = 2.73KOhms
01:14:29.658 -> Increasing, counter = 28, new resistance = 2.83KOhms
01:14:29.753 -> Increasing, counter = 29, new resistance = 2.93KOhms
01:14:29.845 -> Increasing, counter = 30, new resistance = 3.03KOhms
01:14:29.984 -> Increasing, counter = 31, new resistance = 3.13KOhms
01:14:30.078 -> Increasing, counter = 32, new resistance = 3.23KOhms
01:14:30.172 -> Increasing, counter = 33, new resistance = 3.33KOhms
01:14:30.263 -> Increasing, counter = 34, new resistance = 3.43KOhms
01:14:30.357 -> Increasing, counter = 35, new resistance = 3.54KOhms
01:14:30.452 -> Increasing, counter = 36, new resistance = 3.64KOhms
01:14:30.591 -> Increasing, counter = 37, new resistance = 3.74KOhms
01:14:30.684 -> Increasing, counter = 38, new resistance = 3.84KOhms
01:14:30.775 -> Increasing, counter = 39, new resistance = 3.94KOhms
01:14:30.867 -> Increasing, counter = 40, new resistance = 4.04KOhms
01:14:30.960 -> Increasing, counter = 41, new resistance = 4.14KOhms
01:14:31.098 -> Increasing, counter = 42, new resistance = 4.24KOhms
01:14:31.191 -> Increasing, counter = 43, new resistance = 4.34KOhms
01:14:31.285 -> Increasing, counter = 44, new resistance = 4.44KOhms
01:14:31.378 -> Increasing, counter = 45, new resistance = 4.55KOhms
01:14:31.472 -> Increasing, counter = 46, new resistance = 4.65KOhms
01:14:31.610 -> Increasing, counter = 47, new resistance = 4.75KOhms
01:14:31.703 -> Increasing, counter = 48, new resistance = 4.85KOhms
01:14:31.797 -> Increasing, counter = 49, new resistance = 4.95KOhms
01:14:31.889 -> Increasing, counter = 50, new resistance = 5.05KOhms
01:14:31.982 -> Increasing, counter = 51, new resistance = 5.15KOhms
01:14:32.119 -> Increasing, counter = 52, new resistance = 5.25KOhms
01:14:32.210 -> Increasing, counter = 53, new resistance = 5.35KOhms
01:14:32.304 -> Increasing, counter = 54, new resistance = 5.45KOhms
01:14:32.400 -> Increasing, counter = 55, new resistance = 5.56KOhms
01:14:32.494 -> Increasing, counter = 56, new resistance = 5.66KOhms
01:14:32.588 -> Increasing, counter = 57, new resistance = 5.76KOhms
01:14:32.727 -> Increasing, counter = 58, new resistance = 5.86KOhms
01:14:32.818 -> Increasing, counter = 59, new resistance = 5.96KOhms
01:14:32.912 -> Increasing, counter = 60, new resistance = 6.06KOhms
01:14:33.007 -> Increasing, counter = 61, new resistance = 6.16KOhms
01:14:33.100 -> Increasing, counter = 62, new resistance = 6.26KOhms
01:14:33.194 -> Increasing, counter = 63, new resistance = 6.36KOhms
01:14:33.333 -> Increasing, counter = 64, new resistance = 6.46KOhms
01:14:33.428 -> Increasing, counter = 65, new resistance = 6.57KOhms
01:14:33.519 -> Increasing, counter = 66, new resistance = 6.67KOhms
01:14:33.612 -> Increasing, counter = 67, new resistance = 6.77KOhms
01:14:33.704 -> Increasing, counter = 68, new resistance = 6.87KOhms
01:14:33.842 -> Increasing, counter = 69, new resistance = 6.97KOhms
01:14:33.935 -> Increasing, counter = 70, new resistance = 7.07KOhms
01:14:34.027 -> Increasing, counter = 71, new resistance = 7.17KOhms
01:14:34.120 -> Increasing, counter = 72, new resistance = 7.27KOhms
01:14:34.212 -> Increasing, counter = 73, new resistance = 7.37KOhms
01:14:34.351 -> Increasing, counter = 74, new resistance = 7.47KOhms
01:14:34.444 -> Increasing, counter = 75, new resistance = 7.58KOhms
01:14:34.538 -> Increasing, counter = 76, new resistance = 7.68KOhms
01:14:34.630 -> Increasing, counter = 77, new resistance = 7.78KOhms
01:14:34.724 -> Increasing, counter = 78, new resistance = 7.88KOhms
01:14:34.863 -> Increasing, counter = 79, new resistance = 7.98KOhms
01:14:34.954 -> Increasing, counter = 80, new resistance = 8.08KOhms
01:14:35.046 -> Increasing, counter = 81, new resistance = 8.18KOhms
01:14:35.139 -> Increasing, counter = 82, new resistance = 8.28KOhms
01:14:35.233 -> Increasing, counter = 83, new resistance = 8.38KOhms
01:14:35.326 -> Increasing, counter = 84, new resistance = 8.48KOhms
01:14:35.464 -> Increasing, counter = 85, new resistance = 8.59KOhms
01:14:35.557 -> Increasing, counter = 86, new resistance = 8.69KOhms
01:14:35.649 -> Increasing, counter = 87, new resistance = 8.79KOhms
01:14:35.742 -> Increasing, counter = 88, new resistance = 8.89KOhms
01:14:35.835 -> Increasing, counter = 89, new resistance = 8.99KOhms
01:14:35.975 -> Increasing, counter = 90, new resistance = 9.09KOhms
01:14:36.069 -> Increasing, counter = 91, new resistance = 9.19KOhms
01:14:36.163 -> Increasing, counter = 92, new resistance = 9.29KOhms
01:14:36.257 -> Increasing, counter = 93, new resistance = 9.39KOhms
01:14:36.350 -> Increasing, counter = 94, new resistance = 9.49KOhms
01:14:36.444 -> Increasing, counter = 95, new resistance = 9.60KOhms
01:14:36.584 -> Increasing, counter = 96, new resistance = 9.70KOhms
01:14:36.675 -> Increasing, counter = 97, new resistance = 9.80KOhms
01:14:36.767 -> Increasing, counter = 98, new resistance = 9.90KOhms
01:14:36.860 -> Increasing, counter = 99, new resistance = 10.00KOhms
*/

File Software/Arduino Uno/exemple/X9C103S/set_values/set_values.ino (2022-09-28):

//012-Amesis-ColdStartE85 
//v0.01 
//25/08/2022
#include <LapX9C10X.h>
/*                                                                                                                                     
 * This example assumes you're using an X9C103 (10k) chip. For other variants,
 * Change the value in the line:
 *   LapX9C10X led(INCPIN, UDPIN, CSPIN, LAPX9C10X_X9C103);
 * to one of:
 * LAPX9C10X_X9C102       (1k)
 * LAPX9C10X_X9C103       (10k)
 * LAPX9C10X_X9C503       (50k)
 * LAPX9C10X_X9C104       (100k)
 *
 * The chip is connected to the Arduino like this:
 * 1 - !INC - pin 5
 * 2 - U/!D - pin 6
 * 7 - !CS  - pin 7
 * (! indicates that the thing following has a line over the top, called a bar.)
 *   
 * The other pins on the chip must be wired like this:
 * 8 - VCC - 5/3.3V
 * 3 - VH  - 5/3.3V
 * 4 - VSS - GND
 * 6 - VL  - GND
 * 5 - VW  - Output: 680 Ohm resistor to an LED, the other terminal
 *           of the LED connected to GND This value may seem high,
 *           but the maximum steady state wiper current of the chip
 *           is 4.4mA (8.8mA peak for 10 seconds). 680 Ohms - assuming
 *           a 5V supply, and an LED forward voltage drop of 2V, gives 
 *           us almost dead on 4.4mA worst case current (when the wiper
 *           is at the top).
 *           If you want to get the brightest you can, use this formula
 *           for the resistor value (in kilohms), where VCC is the 
 *           supply voltage, and VLED is the LED forward voltage drop:
 *           
 *                R = (VCC - VLED) 
 *                    ------------
 *                        4.4
 *
 * If you use different pins, just change the defines below
 *
 */

#define CSPIN 7
#define INCPIN 5
#define UDPIN 6


LapX9C10X led(INCPIN, UDPIN, CSPIN, LAPX9C10X_X9C103);

void setup() {
  Serial.begin(115200);
  //Serial.setTimeout(30000); // A voir si bloquent ou pas
  //Serial.println("Starting");  
  led.begin(99);
  delay(1000);

}

void loop() {
  //uint8_t counter;
  float resistance;
  
 /* Serial.print("Enter counter value: ");
  counter = Serial.parseInt();
  Serial.println(counter);
  led.set(counter);
  Serial.print("Counter = ");
  Serial.print(led.get());
  Serial.print(", resistance = ");
  Serial.print(led.getK());
  Serial.println("KOhms");
  */

 // Serial.print("Enter resistance in kOhms: ");
  
  Serial.print("J'envoie ");
  resistance = 5;
  Serial.print(resistance);
  Serial.println(" kOhms ");

  Serial.print("Je reçoi ");
  led.set(resistance);
  //Serial.print(led.get());
  Serial.print(led.getK());
  Serial.println("KOhms");
  delay (1000);
}

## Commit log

2022-08-25 Mise place du projet
    Creation des 1er fichier
    [012-Amesis-ColdSartE85.kicad_pcb, 012-Amesis-ColdSartE85.kicad_sch]
2022-08-25 Update 012-Amesis-ColdStartE85.ino
    Debut de creation du fichier
2022-08-25 creation de la vertion v0.2
    Création d'un v0.02
2022-08-25 Create SharedScreenshot.jpg
    schemat de la sonde de temps Liqui de refroidissement
2022-08-25 Create sonde t.jpg
    mise en ligne de la sonde data
2022-08-28 Creation du code arduino de teste
2022-09-09 impor de la savegarde
    [012-Amesis-ColdSartE85.kicad_pcb, 012-Amesis-ColdSartE85.kicad_sch]
2022-09-15 kicad en cour
    [012-Amesis-ColdSartE85.kicad_sch]
2022-09-20 Création du PCB
    En cour. le controleur de rootage affiche quelques erreurs
    [012-Amesis-ColdSartE85.kicad_pcb, 012-Amesis-ColdSartE85.kicad_sch]
2022-09-28 PCB prèsque fini (qr code a modifier
    [012-Amesis-ColdSartE85.kicad_pcb]
2022-09-28 Debut du code de test du module potar numerique
2022-09-28 Code Arduino Module v0.01 Alfa ok
    [012-Amesis-ColdSartE85.kicad_pcb]
2022-09-29 maj
    pcb fini
    visu fini
    iBom fini HWv.0.01
    [012-Amesis-ColdSartE85.kicad_pcb, 012-Amesis-ColdSartE85.kicad_sch]
2022-09-29 maj pcb
2022-10-01 maj pcb et code arduino avec jp et sonde iat
    [012-Amesis-ColdSartE85-B_Cu.gbr, 012-Amesis-ColdSartE85-B_Mask.gbr, 012-Amesis-ColdSartE85-B_Paste.gbr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]
2022-10-03 code v0.02
    termista
    [012-Amesis-ColdSartE85-B_Cu.gbr, 012-Amesis-ColdSartE85-B_Mask.gbr, 012-Amesis-ColdSartE85-B_Paste.gbr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]
2022-10-09 Update 012-Amesis-ColdStartE85.ino
    finalisation du code, reste a faire la routine en cas de DTC = 1
2022-10-09 Update 012-Amesis-ColdStartE85.ino
    correction d'un int en long pour voir plus de temps
    [012-Amesis-ColdStartE85.ino]
2022-10-09 Création de la version V1.00Béta
    Près a faire feu pour des teste réel
2022-10-29 FirmWare v1.03 OK avec HW v0.01Dev
    Création d'une version de developeur et une vertion utilisateur pour le client. La vertion utilisateur et la meme que la dev mais sans l'info sur la console pour la valeur de la sonde de temperature.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
2022-11-02 Création v1.031 SW
    Supression du delay dans le setup
    commande du lap a 0 ohm plus haut dans le setup
2022-11-03 correction sonde température additionnel
    [012-Amesis-ColdStartE85.ino]
2022-11-04 Manuel d'utilisation
    [012-Amesis-ColdSartE85_HWv0.01.kicad_pcb, 012-Amesis-ColdSartE85_HWv0.01.kicad_sch]
